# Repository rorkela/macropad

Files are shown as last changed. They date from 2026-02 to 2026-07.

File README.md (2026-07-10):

# EE2504: Hybrid Macropad (Wired + Dongle)

## Team

| Name | Roll Number |
|---|---|
| Sarthak Kumar Mishra |EE24BTECH11221|
| Naman Singh |EE24BTECH11216|
| Dhawal Saini |EE24BTECH11015|
| Sidharth V |EE24BTECH11224|
| Vantaku Sai Yashwant |EE24BTECH11225|
| Sriram Nulu |EE24BTECH11217|

## Details
- 2 Layer PCB for Macropad+Dongle Pair
- STM32F103C8T6 Based
- Programmed with `libopencm3`
- ssd1306 display integrated
- CAD Model designed to be 3D Printed for keycaps, encoder caps and casing.
- `microui` based key-map programming interface

## Instruction
1. Make the libraries (`libopencm3`)
2. Make and flash bootloader using `make flash`
3. Make and flash macropad firmware using `make flash` or the dfu script
4. Generate keymaps and flash using `mapping_gen`
# Current Status
- [x] PCB Ordered
## Wired
- [x] Bootloader Firmware
- [x] USB HID Firmware
- [x] DFU Firmware
- [x] Encoder Firmware
- [x] Display Firmware
- [x] All module integration
- [x] Multi key mapping
- [ ] Multi key sequential mapping

## Wireless
- [x] Dongle testing
- [x] nRF24L01 Firmware
- [ ] Battery Charging check
- [ ] Soldering SMD Mosfet + nRF modules
- [ ] Replacing PROG resistor for TP4056 module
- [ ] Complete Integration
## Other
- [x] Mapping generation and flashing with DFU
- [x] GUI
- [ ] Size Optimization for keymaps

## Images



## Links
- [CAD Model (Onshape)](https://cad.onshape.com/documents/8695aacad1c4b6aaf32709eb/w/c4719be3eaa84105acadf71a/e/89d918a88e3d346d4846fa41)

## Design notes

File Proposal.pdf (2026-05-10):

# Project Proposal: Design of a Hybrid-Mode Programmable Mechanical Macropad

EE24BTECH11224 Sidharth V
EE24BTECH11225 V Sai Yashwant EE24BTECH11221 Sarthak Mishra EE24BTECH11217 N Sri Ram
EE24BTECH11216 Naman Singh EE24BTECH11015 Dhawal Saini

# Github Link (https://github.com/rorkela/macropad)

## Contents

## Problem Statement

The modern technical workflow on computers relies heavily on complex, multi-key shortcuts. While commerical macro-input solutions, like the macropads exist, they present three critical barriers:

- High Cost-to-Value Ratio: Entry-level wired macropad often exceed ₹3,000. Our design can be cheaper per unit if ordered in bulk.
- Reliability & Software Constraints: Most affordable options are imported with closed-source software that presents reliability issues.
- Lack of Flexibility: They offer limited firmware customizability, minimizing the flexibility of usage in changing profiles, cross-platform connections, etc.
- Project Objective: To address workflow inefficiencies on computers by developed a power-efficient, dual mode (wireless + wired), and cost-effective Macropad.

## Proposed Solution

To bridge this gap, we propose to develop a Hybrid-Mode Custom Mechanical Macropad. This project prioritizes making low-latency and programmable macropad.

Key Features/Objectives:
- Mechanical Keys and Rotary Encoders: 9-key mechanical input array and dual rotary encoders to provide tactile, high-precision shortcuts.
- Dual-Path Connectivity: Transition between wired USB protocol and a low-latency 2.4GHz wireless link using the nRF24L01 protocol.
- Low Latency: By utilizing a Direct-Mapped GPIO Architecture instead of a scannable matrix, the devices reduces latency and achieves near true N-Key Rollover (NKRO) and eliminates the problems like ghosting (failing to detect pressed keys) and phantom keys (detecting unpressed keys).
- Programmable Firmware: A dedicated OLED display to display the the current profile, i.e, the key mapping and dedicated rotary encoder to switch profiles.
- Platform-Agnostic and Standard HID Device Functionality.
- Replaceable Hot Keys: Using hot-swappable mechanical sockets to replace physical keys whenever required.

## Device Architecture

This Macropad is built around STM32F103C8T6 (Cortex-M3) microcontroller, selected for it’s superior processing power compared to 8-bit alternatives and sufficient GPIO count for scanning the key matrix and the interfaces. The architecture is primarily split into two primary parts:
- The Macropad: Integrates the IO interface, the Power Management System and the Communication Module.
- The Dongle: A compact USB-interfaced unit, which receives data packets from the Macropad and translates to the standard HID commands.

### Block Diagram

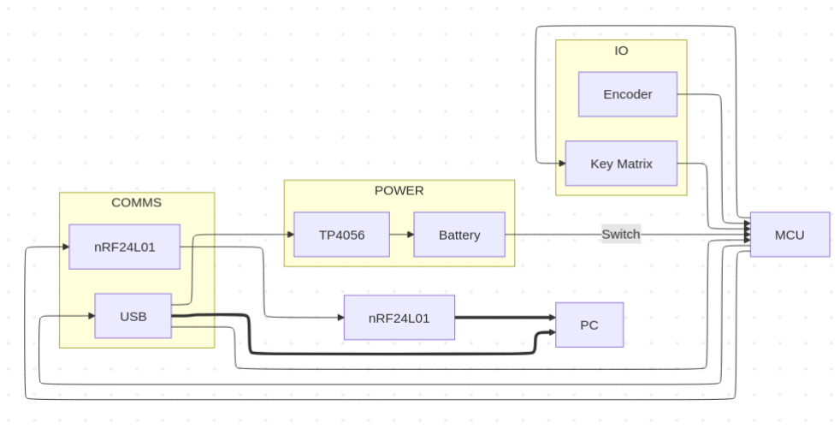
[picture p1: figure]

### Communication

This design comes with dual-modes for communication, allowing the user to switch between the wired USB and the standard 2.4GHz wireless mode.

Wired Mode
- The microcontroller automatically works in wired mode when connected via USB, i.e, if a 5V VBUS signal is detected.
- Dataflow: Key Matrix → STM32 → USB Data Lines (D + / D −) → PC
- The Macropad uses the incoming power from the port and the TP4056 power module simultaneously recharge the battery in the wired mode.
- The design follows the standard schematics for the USB 2.0 Type-C ports.

Wireless Mode
- The microcontroller automatically works in wireless mode when not connected via USB and switches to battery power.
- The nRF24L01 module is used for transmitting and receiving via the SPI (Serial Peripheral Interface) protocol.
- The design follows the following datasheet https://www.elprocus.com/nrf24l01/ , which includes the connections to the microcontroller.

Dongle
- The Dongle uses separate nRF24L01 module and microcontroller for receiving and handling the HID respectively.
- The nRF24L01 and microcontroller communicate via the SPI protocol.
- The dongle can be connected to 6 different devices simultaneously.

### Power Management

The design supports seamless transitions between battery power (wired mode) and USB power (wireless mode).

Charging Circuit and Power Path Logic
- TP4056 Lithium-ion battery charger receives 5V DC from the USB Type-C port.
- The TP4056 schematic is designed on the master schematic instead of using the separate IC.
- An additional Diode protection circuitry, acting as a MUX, is used to protect the battery from the simultaneous charging and discharging activities. This ensures that the Macropad load uses the 5V USB power in wired mode and 3.7V Li-ion battery in wireless mode.
- In wireless mode, the Macropad load uses the battery power. TP4056 module manages this switching.

Voltage Regulation(5V/3.7V → 3.3V)
- This design includes both buck module and an LDO module.
- The Buck module is the primary regulator, preferred over the LDO module, because of its power efficiency and lower power dissipation.
- An LDO module is used as a safety alternative for voltage regulation.

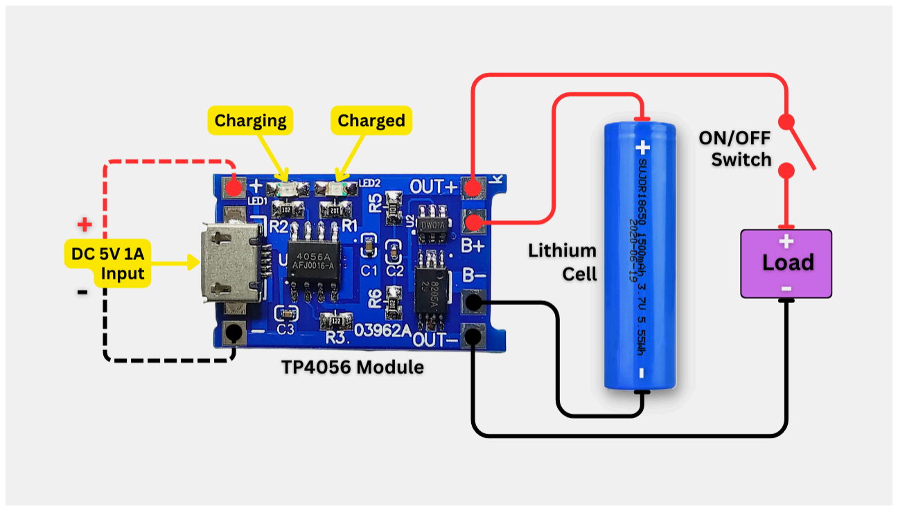
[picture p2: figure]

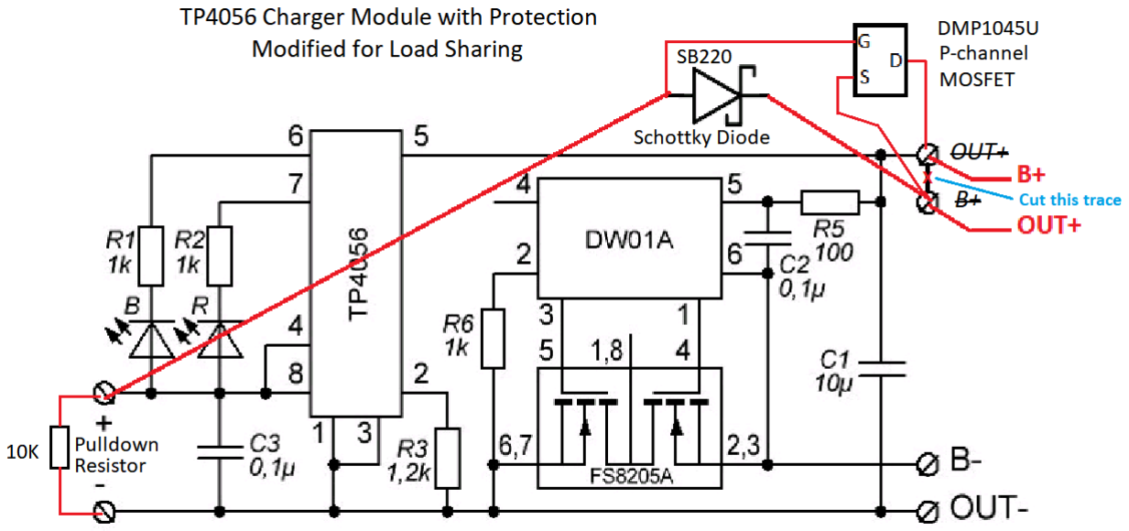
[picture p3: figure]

Figure 1: Reference: Arduino Forums (https://forum.arduino.cc/t/tp4056-circuit-schematic/1404367/8)

Efficiency and Battery Life
- Assuming worst case current draw to be 200mA and under constant use(nRF module does not sleep+Active display+MCU under load) and 2600MAh battery life. If we use 60% of the effective battery life, total uptime comes out to be 7.8 Hours.
- Under Idle situations may expect 24+ hours but requires actual hardware implementation to test.

### I/O Interface

The I/O interface is the bridge between user and the microcontroller. This part comprises of Mechanical Keys, 2 Rotary Encoder, and the OLED Display.

Direct Mapped Key Inputs
- This design uses Direct-Mapped GPIO configuration for the 9 mechanical switches.
- Each key is directly connected to a dedicated GPIO pin.
- This results in near-zero latency and a true N-Key Rollover (NKRO) as every key is sensed independently unlike for key matrix, where the microcontroller scans for key presses.
- Hot-swap Keys: The keys are mounted via mechanical sockets, allowing install keys without soldering.

Rotary Encoder
- Each encoder has 5 pins: +3.3V, GND, CLK (Phase A), DT (Phase B), SW.
- Quadrature Signals (CLK & DT): These signals transmit “out-of-phase” pulses.
- Determining direction: The Clockwise rotation results in Phase A going high before Phase B and vice-versa for Counter-Clockwise rotation.
- Integrated Push Switch (SW): It is used for ?

Display
- A 0.96-inch OLED display is used to display: Active Profile: Current-Key map configuration. Connection Mode: Wired/Wireless Battery Life remaining (in %)
- The display interfaces via I2C protocol, requiring only two wires (SDA and SCL) to handle the visual data.
- The firmware inside STM32 process the input signals for the display.

### Firmware

Bootloader
- A custom USB-DFU bootloader is used to to enable firmware upgrade and programmable keys through USB.

HID
- The macropad implements two HID interfaces, keyboard and system control.
- The keyboard interface is used for macros that use the keys present in a regular 106 key keyboard.
- The system control interface allows other bindings such as device volume, brightness and power controls.
- The code has been tested on Linux and Windows.
- In wireless operation, the macropad sends the usb reports to the dongle, and the dongle acts as a HID device and forwards this report to the host.

Profiles
- The Profiles and key mappings are stored outside the main firmware. The firmware reads the data from memory based on the selected profile.
- This allows changing the key mappings without having to re-flash the main HID firmware

Dongle
- The dongle acts as a USB device with multiple interfaces
- The code can be extended to support multiple device connections, using a different interface for each device connected to the nRF24L01

## Schematic

This is the final schematic.

NRST 7 | BOOT0 44 | PD0 5 | PD1 6 | PC13 2 | PC14 3 | PC15 4 | PB0 18 | PB1 19 | PB2 20 | PB3 39 | PB4 40 | PB5 41 | PB6 42 | PB7 43 | PB8 45 | PB9 46 | PB10 21 | PB11 22 | PB12 25 | PB13 26 | PB14 27 | PB15 28 | VBAT

# 10k GND GND

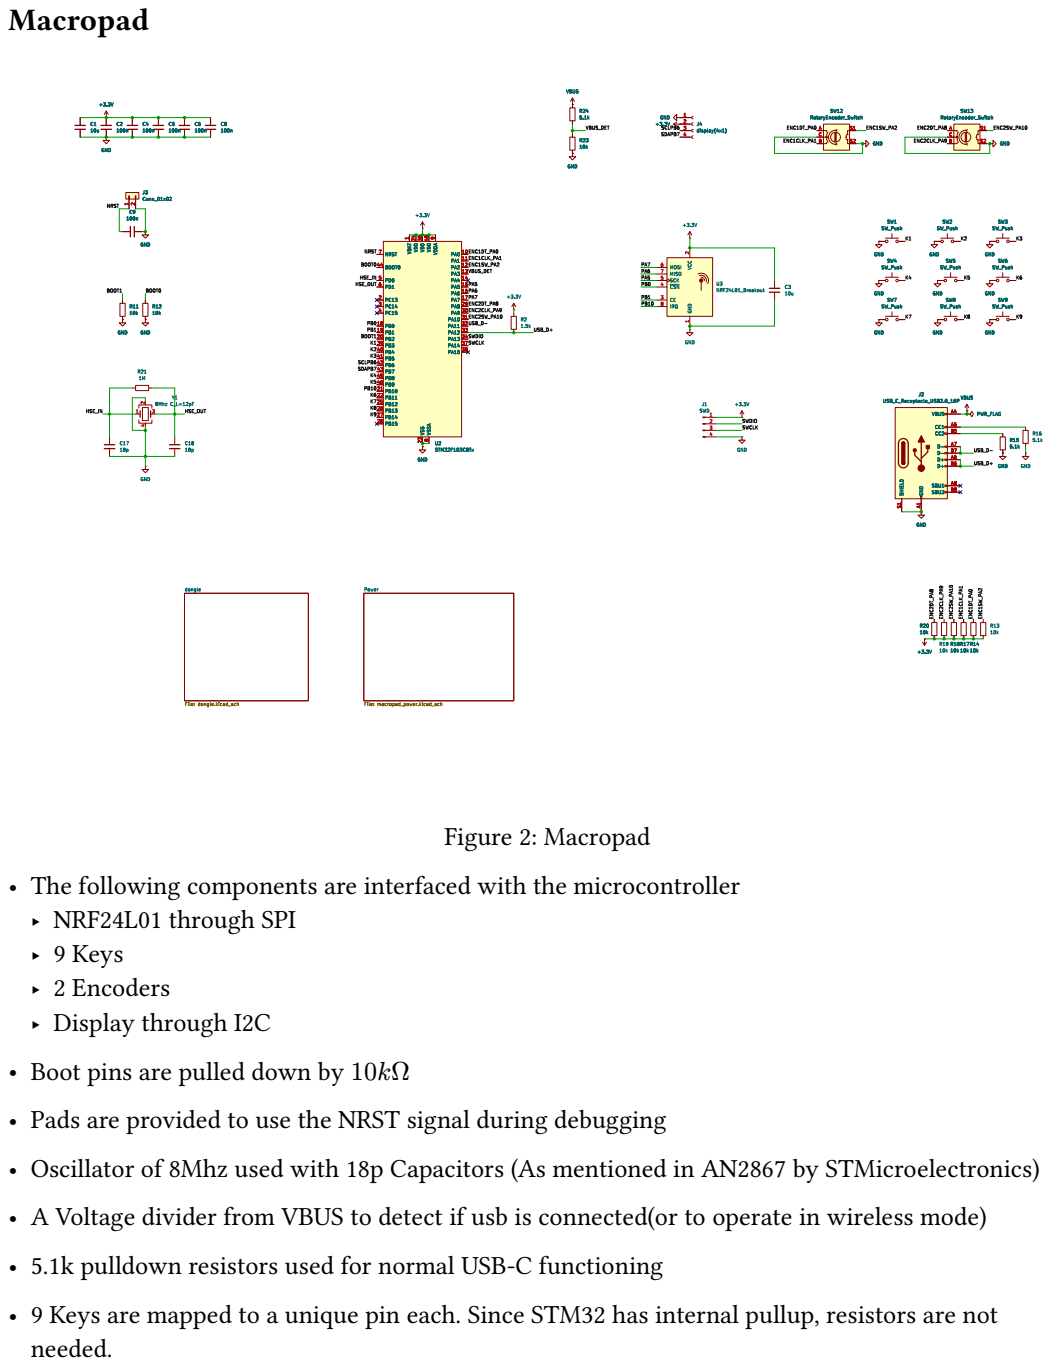
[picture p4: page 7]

1 VDD 24 VDD 36 VSS 23 VDD 48 VSSA

• The following components are interfaced with the microcontroller
‣ NRF24L01 through SPI
‣ 9 Keys
‣ 2 Encoders
‣ Display through I2C

• Boot pins are pulled down by 10kΩ

• Pads are provided to use the NRST signal during debugging

• Oscillator of 8Mhz used with 18p Capacitors (As mentioned in AN2867 by STMicroelectronics)

• A Voltage divider from VBUS to detect if usb is connected(or to operate in wireless mode)

• 5.1k pulldown resistors used for normal USB-C functioning

• 9 Keys are mapped to a unique pin each. Since STM32 has internal pullup, resistors are not
needed.

18p | C13
10n | C20

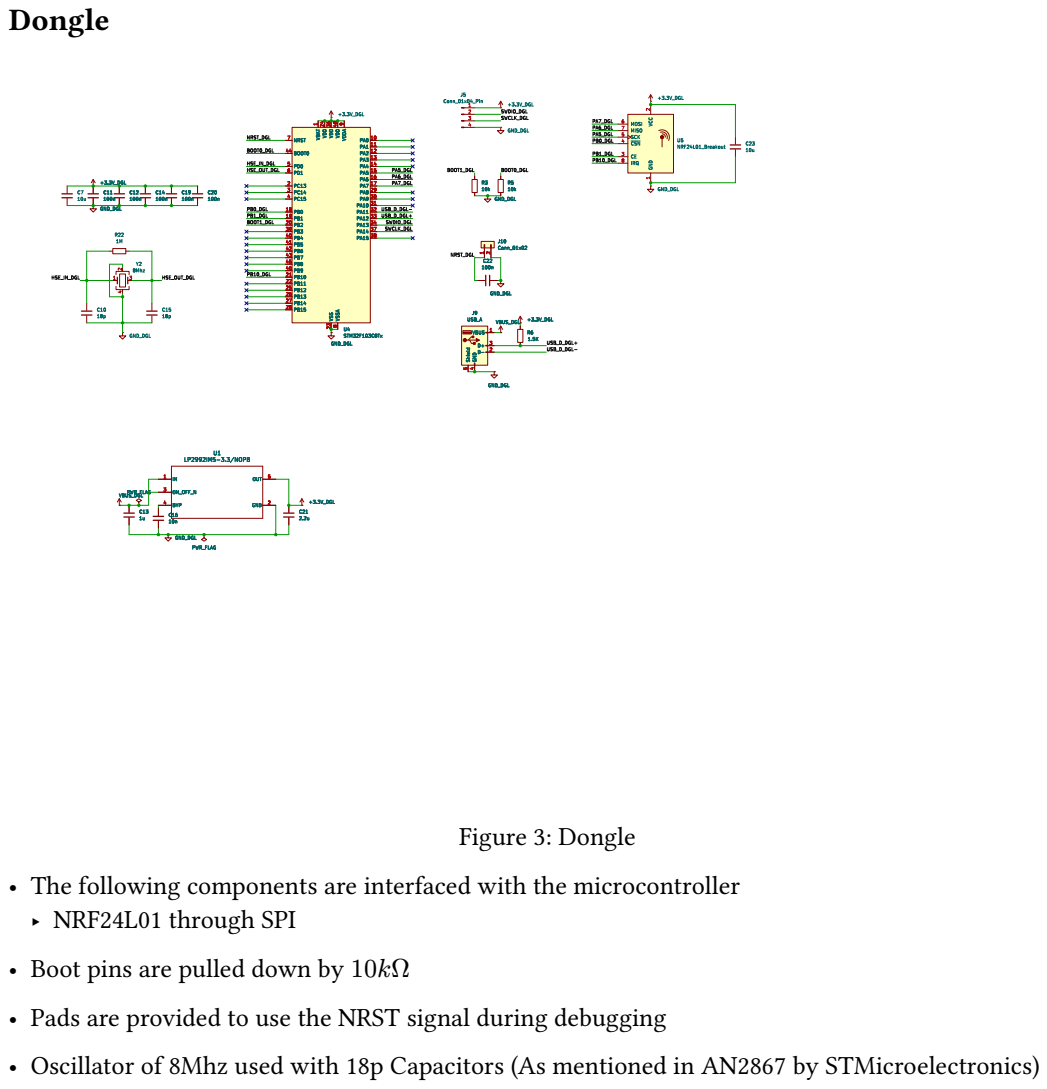
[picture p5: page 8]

1 VDD 24 VDD 36 VSS 23 VDD 48 VSSA

• The following components are interfaced with the microcontroller
‣ NRF24L01 through SPI

• Boot pins are pulled down by 10kΩ

• Pads are provided to use the NRST signal during debugging

• Oscillator of 8Mhz used with 18p Capacitors (As mentioned in AN2867 by STMicroelectronics)

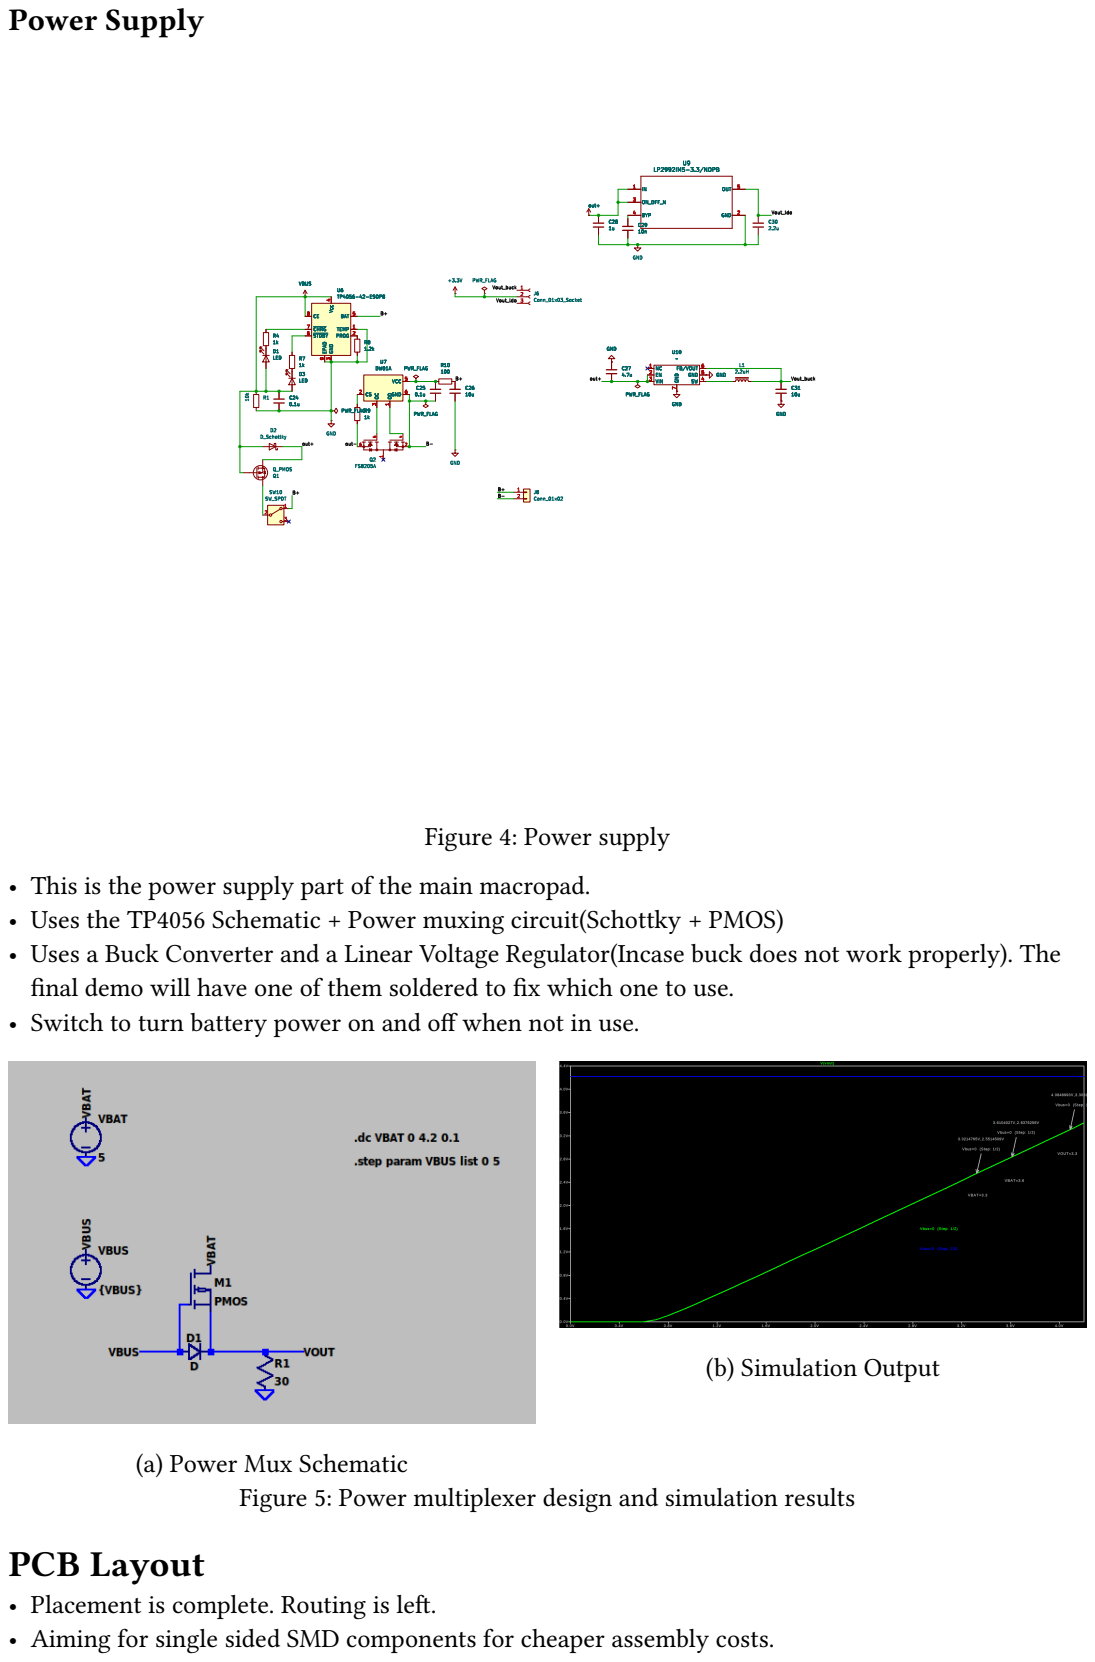
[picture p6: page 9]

7 FB/VOUT 6 GND 5 SW 4 PWR_FLAG

7 FB/VOUT 6 GND 5 SW 4 U10~

• This is the power supply part of the main macropad.
• Uses the TP4056 Schematic + Power muxing circuit(Schottky + PMOS)
• Uses a Buck Converter and a Linear Voltage Regulator(Incase buck does not work properly). The
final demo will have one of them soldered to fix which one to use.
• Switch to turn battery power on and off when not in use.

Figure 5: Power multiplexer design and simulation results

PCB Layout
• Placement is complete. Routing is left.
• Aiming for single sided SMD components for cheaper assembly costs.

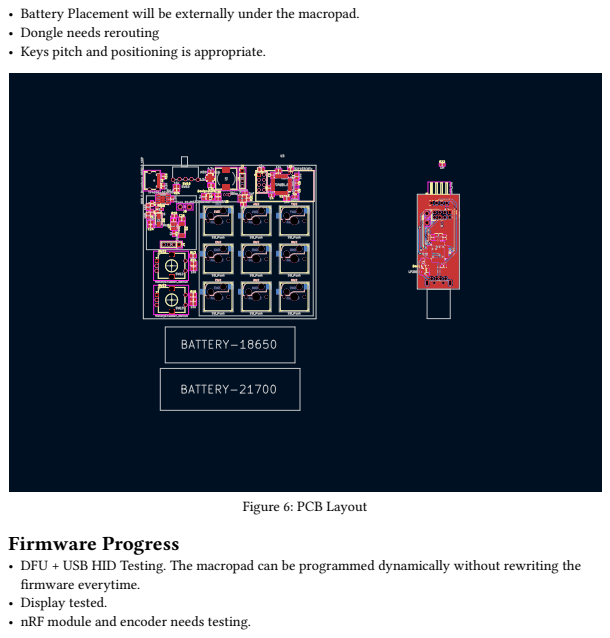
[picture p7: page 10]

• Battery Placement will be externally under the macropad.
• Dongle needs rerouting
• Keys pitch and positioning is appropriate.

Figure 6: PCB Layout

Firmware Progress
• DFU + USB HID Testing. The macropad can be programmed dynamically without rewriting the
firmware everytime.
• Display tested.
• nRF module and encoder needs testing.

## 3D Printing Progress

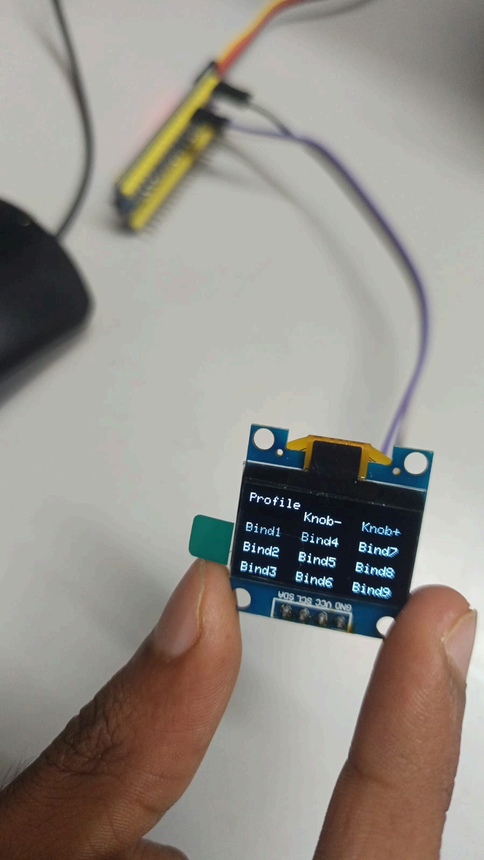
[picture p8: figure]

We did a test 3d print of a key. We will test it later. The model was taken from online (Link). (https://www.printables.com/model/118708-simple-cherry-mx-keycap)

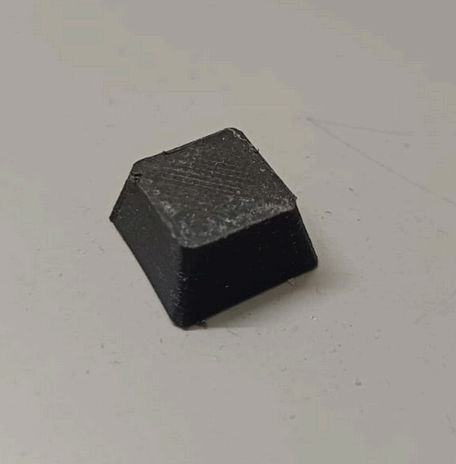
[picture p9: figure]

,

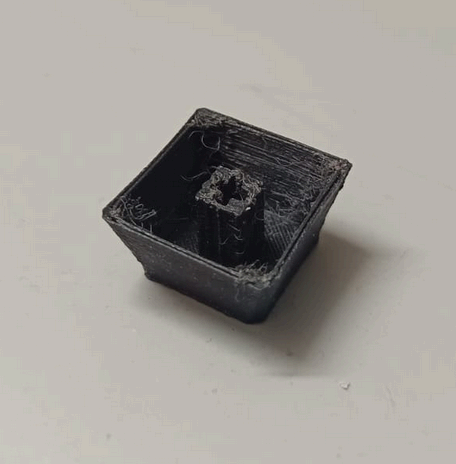
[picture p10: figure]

Figure 8: 3D printed keycap

## Cost Estimates

Sl No | Component Name | Unit Cost (₹) | Qty | Subtotal (₹)
1 | STM32F103C8T6 | 176.00 | 2 | 352.00
2 | M177 NRF24L01 Module | 71.00 | 2 | 142.00
3 | Mechanical Keys (Pack of 10) | 300.00 | 1 | 300.00
4 | Kailh Hot-swap Socket (Pack of 10) | 80.00 | 1 | 80.00
5 | TP4056 Module | 15.00 | 1 | 15.00
6 | Battery Protection (DW01A) | 4.00 | 1 | 4.00
7 | FS8205A Dual MOSFET | 8.00 | 1 | 8.00
8 | TP4056 IC | 7.00 | 1 | 7.00
9 | 0.96 inch OLED Module | 200.00 | 1 | 200.00
10 | Lithium Ion Battery | 0.00 | 1 | 0.00
11 | Rotary Encoder Module | 50.00 | 2 | 100.00
12 | Voltage Regulator (LP2992) | 14.00 | 2 | 28.00
13 | Crystal Oscillator (8MHz) | 10.00 | 2 | 20.00
14 | Buck Converter (RT8010) | 45.48 | 1 | 45.48
15 | USB A Connector | 2.64 | 1 | 2.64
16 | USB-C Receptacle | 3.95 | 1 | 3.95
17 | Schottky Diode (SS34) | 2.00 | 2 | 4.00
18 | PMOS (SI2305CDS) | 10.00 | 1 | 10.00
19 | Slide Switch (SPDT) | 7.00 | 2 | 14.00
20 | Pin Headers (1xN) | 2.00 | 14 | 28.00
21 | Inductor 2.2uH | 15.00 | 1 | 15.00
22 | Cap 4.7uF | 7.00 | 1 | 7.00
23 | Cap 10uF | 6.00 | 9 | 54.00
24 | Res 10K Ohm | 0.35 | 5 | 1.75
25 | Res 1K Ohm | 0.19 | 3 | 0.57
26 | Cap 0.1uF | 1.69 | 14 | 23.66
27 | Res 1.2K Ohm | 0.15 | 1 | 0.15
28 | Res 100 Ohm | 0.40 | 3 | 1.20
29 | Res 1.5k | 1.00 | 2 | 2.00
30 | Res 5.1k | 1.00 | 2 | 2.00
31 | Cap 18pF | 1.36 | 4 | 5.44
32 | Cap 1uF | 1.17 | 2 | 2.34
33 | LEDs (0805) | 1.55 | 4 | 6.20

34 | Cap 10nF | 0.63 | 1 | 0.63
35 | Cap 2.2uF | 1.00 | 1 | 1.00
Grand Total | | | | ₹1,586.04

Note: Lithium ion battery (Sl No 10) is a lab-sourced item and is not included in the total cost.

## Component Availability

Here is the list of components which can readily be procured from Robu.

Sl | Component Name | Part Number | Package | Vendor Link
1 | STM32F103C8T6 | STM32F103C8T6 | LQFP-48 | Robu.in (https://robu.in/product/stm32f103c8t6-lqfp-48-arm-microcontrollers-mcu/)
2 | nRF24L01 Module | NRF24L01 | PCB 4x2 | Robu.in (https://robu.in/product/m177-nrf24l01-2-4ghz-antenna-wireless-transceiver-module/)
3 | Mechanical Keys | Gateron Pro | 5-Pin TH | Meckeys (https://meckeys.com/shop/accessories/keyboard-accessories/key-switches/gateron-mechanical-pro-switch-5pin/)
4 | Kailh Hotswap Socket | CPG151101S11-16 | SMD | Meckeys (https://meckeys.com/shop/accessories/keyboard-accessories/key-switches/kailh-hot-swap-socket/)
5 | TP4056 Module | TP4056 | PCB Module | Robu.in (https://robu.in/product/tp4056-1a-li-ion-lithium-battery-charging-module-with-current-protection-type-c/)
6 | Battery Protection | DW01A | SOT-23-6 | Robu.in (https://robu.in/product/dw01a-4-3v-lithium-ion-lithium-polymer-battery-protection-ic-6pin-sot-23/)
7 | FS8205A MOSFET | FS8205A | SMD | Robu.in (https://robu.in/product/1-month-warranty-398/)
8 | TP4056 IC | TP4056 | SMD | Evelta (https://evelta.com/tp4056-4-2v-1a-li-lon-battery-charger-with-thermal-regulation/)
9 | 0.96″ OLED Module | SSD1306 | PCB 4-pin | Robu.in (https://robu.in/product/0-96-inch-yellow-yellow-blue-oled-lcd-led-display-module/)
10 | Li-ion Battery | Lab ID: AA546 | Cell | Lab Item
11 | Rotary Encoder | KY-040 | 5 Pin Header | Robu.in (https://robu.in/product/m274-360-degree-rotary-encoder-module-brick-sensor/)
12 | Voltage Regulator | LP2992-3.3V | SOT-23-5 | Robu.in (https://robu.in/product/lp2992im5-3-3-nopb-texas-instruments-fixed-ldo-voltage-regulator-2-2v-to-16v-450mv-dropout-3-3vout-250maout-sot-23-5/)
13 | Crystal Oscillator | 8MHz | SMD 3225 | Robu.in (https://robu.in/product/x32258mob4si-yxc-crystal-oscillators-8mhz-surface-mount-crystal-12pf-%c2%b110ppm-%c2%b120ppm-smd3225-4p-crystals-rohs/)
14 | Buck Regulator | RT8010-33GQW | 6-WDFN | DigiKey (https://www.digikey.in/en/products/detail/richtek-usa-inc/RT8010-33GQW/2545950)
15 | USB A Connector | U-G-O4DD | Type A Male | Robu.in (https://robu.in/product/u-g-o4dd-w-1-hroparts-1a-1-4p-male-40%e2%84%8385%e2%84%83-type-a-usb-connectors-rohs/)
16 | USB-C Receptacle | U263-163N | SMD 16P | Robu.in (https://robu.in/product/u263-163n-4ws1735-xkb-5a-1-16p-female-25%E2%84%8385%E2%84%83-type-c-smd-usb-connectors-rohs/)
17 | Schottky Diode | SS34 | DO-214 | Robu.in (https://robu.in/product/ss34-slkor-40v-500mv3a-3a-smado-214ac-schottky-diodes-rohs/)
18 | P-MOSFET | SI2305CDS | SOT-23 | Robu.in (https://robu.in/product/si2305cds-t1-ge3-vishay-si2305cds-t1-ge3-power-mosfet-p-channel-8-v-5-8-a-0-028-ohm-sot-23-surface-mount/)
19 | Slide Switch | SS12F23L5 | Plugin | Robu.in (https://robu.in/product/1-month-warranty-690/)
20 | Pin Headers | 2.54mm Machined | Through Hole | Robu.in (https://robu.in/product/361030115sg111901-jiln-2-54x3-0machined-pin-header-1x15p-180-l11-96-upper-pinpoint0-60-bottom-pinpoint0-50-au1u-pps/)
21 | Inductor 2.2uH | CDRH104R | SMD | Robu.in (https://robu.in/product/cdrh104r-2-2%ce%bch-power-inductor-pack-of-5/)
22 | Cap 4.7uF | GRM188Z71C475 | 0603 | Robu.in (https://robu.in/product/grm188z71c475ke21d-murata-electronics-16v-4-7uf-x7r-%c2%b110-0603-multilayer-ceramic-capacitors-mlcc-smd-smt-rohs/)
23 | Cap 10uF | GRT21BR61C106 | 0805 | Robu.in (https://robu.in/product/grt21br61c106ke01l-murata-electronics-16v-10uf-x5r-%c2%b110-0805-multilayer-ceramic-capacitors-mlcc-smd-smt-rohs/)
24 | Res 10K Ohm | RC0805FR-0710K | 0805 | Robu.in (https://robu.in/product/rc0805fr-0710kl-yageo-res-thick-film-0805-10k-ohm-1-0-125w1-8w-%c2%b1100ppm-c-pad-smd-t-r/)
25 | Res 1K Ohm | AC0603FR-071K | 0603 | Robu.in (https://robu.in/product/ac0603fr-071kl-yageo-res-thick-film-0603-1k-ohm-1-0-1w1-10w-%c2%b1100ppm-c-pad-smd-t-r-automotive-aec-q200/)
26 | Cap 0.1uF | AC0603JRX7R9BB | 0603 | Robu.in (https://robu.in/product/ac0603jrx7r9bb104-yageo-cap-ceramic-0-1uf-50v-x7r-5-pad-smd-0603-125c-automotive-aec-q200-t-r/)
27 | Res 1.2K Ohm | AC0603FR-071K2 | 0603 | Robu.in (https://robu.in/product/ac0603fr-071k2l-yageo-res-thick-film-0603-1-2k-ohm-1-0-1w1-10w-%c2%b1100ppm-c-pad-smd-t-r-automotive-aec-q200/)
28 | Res 100 Ohm | AC0201FR-07100R | 0603 | Robu.in (https://robu.in/product/ac0201fr-07100rl-yageo-smd-chip-resistor-100-ohm-%c2%b1-1-50-mw-0201-0603-metric-thick-film-general-purpose/)
29 | Res 1.5K Ohm | RT0603FRE071K5 | 0603 | Robu.in (https://robu.in/product/rt0603fre071k5l-yageo-100mw-thin-film-resistor-%c2%b150ppm-%e2%84%83-%c2%b11-1-5k%cf%89-0603-chip-resistor-surface-mount-rohs/)
30 | Res 5.1K Ohm | RT0603FRE075K1 | 0603 | Robu.in (https://robu.in/product/rt0603fre075k1l-yageo-100mw-thin-film-resistor-75v-%c2%b150ppm-%e2%84%83-%c2%b11-1-5-1k%cf%89-0603-chip-resistor-surface-mount-rohs/)
31 | Cap 18pF | GCM0335C1H180 | 0603 | Robu.in (https://robu.in/product/gcm0335c1h180fa16d-murata-smd-multilayer-ceramic-capacitor-18-pf-50-v-0201-0603-metric-%c2%b1-1-c0g-np0-gcm/)
32 | Cap 1uF | UMK212B7105K | 0805 | Robu.in (https://robu.in/product/umk212b7105kght-taiyo-cap-ceramic-1uf-50v-x7r-10-pad-smd-0805-125c-low-esr-automotive-aec-q200-t-r/)
33 | LEDs (Red) | 17-21SURC/S530 | 0805 | Robu.in (https://robu.in/product/17-21surc-s530-a3-4t-everlight-elec/)
34 | Cap 10nF | Ceramic MLCC | 0603 | Robu.in (https://robu.in/product/10nf-0603-surface-mount-multilayer-ceramic-capacitor-pack-of-50/)
35 | Cap 2.2uF | TMK107BBJ225 | 0603 | Robu.in (https://robu.in/product/tmk107bbj225kaht-taiyo-cap-ceramic-2-2uf-25v-x5r-10-pad-smd-0603-85c-low-esr-automotive-aec-q200-t-r/)

Item | Count
Keycaps | 9
Macropad Casing | 1
Dongle Casing | 1

Table 1: 3D Printing Estimates

Some expenses in procuring modules for testing before PCB fabrication are not included.

Approximate PCB Quotation

This is based on assembly configuration and very rough PCB Area.

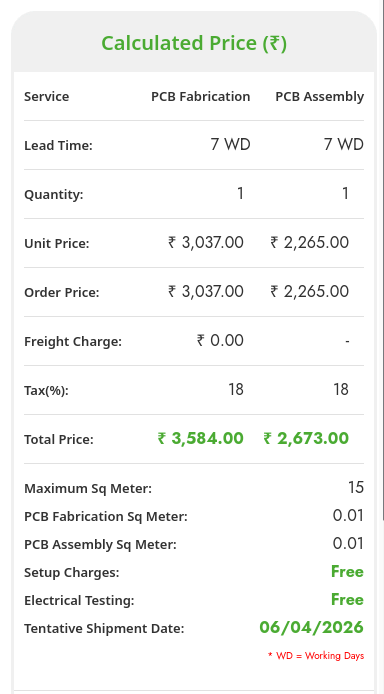
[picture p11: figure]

Figure 9: Approximate PCBPower Quotation

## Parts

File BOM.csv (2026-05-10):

Sl No | Components' name | Components' Value | Manufacturer Part Number (MPN) | Link to Datasheet | Package/Footprint | Quantity | Vendor Link-1 | Vendor Link-2 | Vendor Link-3 | Vendor Link-4
1 | STM32F103C8T6 | 176 | STM32F103C8T6 | https://www.st.com/resource/en/datasheet/stm32f103c8.pdf | SMD LQFP-48 | 2 | https://robu.in/product/stm32f103c8t6-lqfp-48-arm-microcontrollers-mcu/ | https://evelta.com/stm32f103c8t6---32bit-arm-cortex-m3-microcontroller-72mhz-64kb-flash-48-pin-lqfp/ | https://www.digikey.in/en/products/detail/stmicroelectronics/STM32F103C8T6/1646338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
2 | M177 NRF24L01 2.4GHz Antenna Wireless Transceiver Module | 71 | NRF24L01 | https://docs.nordicsemi.com/bundle/nRF24L01P_PS_v1.0/resource/nRF24L01P_PS_v1.0.pdf | PCB(4x2 pins) | 2 | https://robu.in/product/m177-nrf24l01-2-4ghz-antenna-wireless-transceiver-module/ | https://robocraze.com/products/nrf24l01-ultra-low-power-2-4ghz-rf-wireless-transceiver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 | https://probots.co.in/nrf24l01-rf-wireless-transceiver-2-4ghz-module.html | https://quartzcomponents.com/products/nrf24l01-24f-rf-transiver-module
3 | Mechanical Keys(Pack of 10) | 300 | NA | NA | 5 Pin Through Hole | 1(Pack of 10) | https://meckeys.com/shop/accessories/keyboard-accessories/key-switches/gateron-mechanical-pro-switch-5pin/ | https://amzn.in/d/090QFwbe | https://www.amazon.in/Buildcon-Linear-Keyboard-Compatible-Keyboards/dp/B0FQTZMC9R | https://meckeys.com/shop/accessories/keyboard-accessories/key-switches/cherry-mx-rgb-switch/
4 | Kailh Hot-swap Socket(Pack of 10)) | 80 | CPG151101S11-16 | https://www.lcsc.com/product-detail/C5156480.html | SMD | 1(Pack of 10) | https://meckeys.com/shop/accessories/keyboard-accessories/key-switches/kailh-hot-swap-socket/ | https://neomacro.in/products/kailh-mx-hotswap-socket?variant=49467139227926
5 | TP4056 Module | 15 | TP4056 | NA | PCB(Module) | 1 | https://robu.in/product/tp4056-1a-li-ion-lithium-battery-charging-module-with-current-protection-type-c/ | https://robocraze.com/products/tp4056-battery-charger-c-type-module-with-protection-1 | https://robokits.co.in/batteries-chargers/charge-protection-circuit/tp4056-1a-5v-li-ion-battery-charge-discharge-protection-module-type-c-usb | https://quartzcomponents.com/products/tp4056-battery-charging-protection-module-type-c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
6 | Battery Protection (DW01A) | 4 | DW01A | https://mm.digikey.com/Volume0/opasdata/d220001/medias/docus/7833/DW01A%20SOT-23-6.PDF | SMD | 1 | https://robu.in/product/dw01a-4-3v-lithium-ion-lithium-polymer-battery-protection-ic-6pin-sot-23/ | https://www.digikey.in/en/products/detail/shenzhen-slkormicro-semicon-co-ltd/DW01A/28143000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
7 | FS8205A | 8 | FS8205A | https://mm.digikey.com/Volume0/opasdata/d220001/medias/docus/7158/5272_FS8205A.pdf | SMD | 1 | https://robu.in/product/1-month-warranty-398/ | https://www.digikey.in/en/products/detail/evvo/FS8205A/26220994?msockid=33cd2190f636665f1fcb3795f7df6785
8 | TP4056 | 7 | TP4056 | https://www.digikey.com/htmldatasheets/production/2049110/0/0/1/tp4056.html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 | SMD | 1 | https://evelta.com/tp4056-4-2v-1a-li-lon-battery-charger-with-thermal-regulation/ | https://robu.in/product/1-month-warranty-1253/
9 | 0.96 inch Yellow-Blue OLED Display Module | 200 | NA | NA | PCB(4 pins in sequence GND VDD SCK SDA) | 1 | https://robu.in/product/0-96-inch-yellow-yellow-blue-oled-lcd-led-display-module/ | https://quartzcomponents.com/products/oled-display-0-96-inch-i2c-interface-4-pin-blue-ssd1306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 | https://robocraze.com/products/0-96in-oled-display-module-4pin?_pos=1&_sid=e498cf4c5&_ss=r | https://robocraze.com/products/0-96in-oled-display-module-4pin?_pos=1&_sid=821c7db53&_ss=r
10 | Lithium ion battery | available in lab | AA546(Lab item ID),BPK-QC1411 | NA | NA | 1 | https://robu.in/product/samsung-inr18650-25r-2500mah-li-ion-battery/ | https://robu.in/product/dmegc-inr21700-45e-3-7v-4500mah-li-ion-battery/
11 | M274 360-Degree Rotary Encoder Sensor Brick Module | 50 | KY-040 | https://www.alldatasheet.com/datasheet-pdf/pdf/1648739/JOY-IT/KY-040.html | 5 Pin Header | 2 | https://robu.in/product/m274-360-degree-rotary-encoder-module-brick-sensor/ | https://electronicspices.com/product/ky-040-rotary-encoder-module-brick-sensor-for-development-board-360-degree | https://robocraze.com/products/rotary-encoder-module?_pos=1&_sid=a3f2cd847&_ss=r | https://techdelivers.com/360-degree-rotary-encoder-module-m274-brick-sensor-incremental-type-price-india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
12 | Voltage Regulator(LP2992IM5-3.3V) | 14 | LP2992IM5-3.3/NOPB | https://www.ti.com/lit/ds/symlink/lp2992.pdf?ts=1742480137364&ref_url=https%253A%252F%252F | SOT-23-5 | 2 | https://robu.in/product/lp2992im5-3-3-nopb-texas-instruments-fixed-ldo-voltage-regulator-2-2v-to-16v-450mv-dropout-3-3vout-250maout-sot-23-5/
13 | Crystal Oscillator(8MHz) | 10 | X32258MOB4SI | https://www.lcsc.com/datasheet/C2682775.pdf | SMD | 2 | https://robu.in/product/x32258mob4si-yxc-crystal-oscillators-8mhz-surface-mount-crystal-12pf-%c2%b110ppm-%c2%b120ppm-smd3225-4p-crystals-rohs/
14 | buck(RT8010-33GQW) | 45.48 | RT8010-33GQW | https://www.richtek.com/assets/product_file/RT8010=RT8010A/DS8010A-13.pdf | SMD(6-WDFN) | 1 | https://www.digikey.in/en/products/detail/richtek-usa-inc/RT8010-33GQW/2545950
15 | USB A | 2.64 | U-G-O4DD-W-1-Hroparts-1A | https://robu.in/wp-content/uploads/2025/08/C2910540.pdf | https://robu.in/wp-content/uploads/2025/08/C2910540.pdf | 1 | https://robu.in/product/u-g-o4dd-w-1-hroparts-1a-1-4p-male-40%e2%84%8385%e2%84%83-type-a-usb-connectors-rohs/ | https://robu.in/product/usb-a-type-plug-male-pcb-r-a-connector-pack-of-5/
16 | USB - c receptacle | 3.95 | U263-163N-4WS1735-XKB-5A | https://robu.in/wp-content/uploads/2025/08/C2931473.pdf https://www.helloxkb.com/public/images/pdf/U263-163N-4WS1735.pdf | https://robu.in/wp-content/uploads/2025/08/C2931473.pdf | 1 | https://robu.in/product/u263-163n-4ws1735-xkb-5a-1-16p-female-25%E2%84%8385%E2%84%83-type-c-smd-usb-connectors-rohs/
17 | schottky diode | 2 | SS34 | https://www.onsemi.com/download/data-sheet/pdf/ss39-d.pdf | DO-214 | 2 | https://robu.in/product/ss34-slkor-40v-500mv3a-3a-smado-214ac-schottky-diodes-rohs/ | https://www.digikey.com/en/products/detail/onsemi/SS34/1052384?msockid=33cd2190f636665f1fcb3795f7df6785 | https://www.digikey.in/en/products/detail/diotec-semiconductor/SB220/22191291
18 | PMOS(SI2305CDS-T1-GE3) | 10 | SI2305CDS-T1-GE3 | https://robu.in/wp-content/uploads/2025/06/R231218.pdf | SOT-23 | 1 | https://robu.in/product/si2305cds-t1-ge3-vishay-si2305cds-t1-ge3-power-mosfet-p-channel-8-v-5-8-a-0-028-ohm-sot-23-surface-mount/ | https://www.mouser.in/ProductDetail/Vishay-Semiconductors/SI2305CDS-T1-GE3?qs=45wPT2wjtGlJ9EjSomimkg%3D%3D
19 | SS12F23L5-XKB-300mA Single Pole Double Throw (SPDT) 50V 50V 300mA 10,000 times Black Plugin Slide Switches ROHS | 7 | SS12F23L5 | https://www.lcsc.com/datasheet/C2884749.pdf | https://www.lcsc.com/datasheet/C2884749.pdf | 2 | https://robu.in/product/1-month-warranty-690/
20 | Pin Headers(Any 1xN) | 14 | 361030115SG111901 |  | 2.54mm Through Hole | 2 | https://robu.in/product/361030115sg111901-jiln-2-54x3-0machined-pin-header-1x15p-180-l11-96-upper-pinpoint0-60-bottom-pinpoint0-50-au1u-pps/ | https://robu.in/product/361030130sg111901-jiln-2-54x3-0machined-pin-header-1x30p-180-l11-96-upper-pinpoint0-60-bottom-pinpoint0-50-au1u-pps/
21 | Inductor 2.2uH | 15 | CDRH104R 2.2uH |  | SMD | 1 | https://robu.in/product/cdrh104r-2-2%ce%bch-power-inductor-pack-of-5/ | https://sharvielectronics.com/product/cdrh104r-2-2uh-smd-power-inductor/
22 | Cap 4.7uF | 7 | GRM188Z71C475KE21D |  | SMD-0603 | 1 | https://robu.in/product/grm188z71c475ke21d-murata-electronics-16v-4-7uf-x7r-%c2%b110-0603-multilayer-ceramic-capacitors-mlcc-smd-smt-rohs/
23 | Cap 10uF | 9 | GRT21BR61C106KE01L |  | SMD-0805 | 6 | https://robu.in/product/grt21br61c106ke01l-murata-electronics-16v-10uf-x5r-%c2%b110-0805-multilayer-ceramic-capacitors-mlcc-smd-smt-rohs/
24 | Res 10K Ohm | 0.32 | RC0805JR-0710KL |  | SMD-0805 | 25 | https://robu.in/product/rc0805jr-0710kl-yageo-res-thick-film-0805-10k-ohm-5-0-125w1-8w-%c2%b1100ppm-c-pad-smd-t-r/ | https://robu.in/product/rc0805jr-0710kl-yageo-res-thick-film-0805-10k-ohm-5-0-125w1-8w-%c2%b1100ppm-c-pad-smd-t-r/
25 | Res 1K ohm | 0.19 | AC0603FR-071KL |  | SMD-0603 | 3 | https://robu.in/product/ac0603fr-071kl-yageo-res-thick-film-0603-1k-ohm-1-0-1w1-10w-%c2%b1100ppm-c-pad-smd-t-r-automotive-aec-q200/
26 | Cap 0.1uF | 1.69 | AC0603JRX7R9BB104 |  | SMD-0603 | 15 | https://robu.in/product/ac0603jrx7r9bb104-yageo-cap-ceramic-0-1uf-50v-x7r-5-pad-smd-0603-125c-automotive-aec-q200-t-r/
27 | Res 1.2K ohm | 0.15 | AC0603FR-071K2L |  | SMD-0603 | 1 | https://robu.in/product/ac0603fr-071k2l-yageo-res-thick-film-0603-1-2k-ohm-1-0-1w1-10w-%c2%b1100ppm-c-pad-smd-t-r-automotive-aec-q200/
28 | Res 100 ohm | 0.4 | AC0201FR-07100RL |  | SMD-0603 | 3 | https://robu.in/product/ac0201fr-07100rl-yageo-smd-chip-resistor-100-ohm-%c2%b1-1-50-mw-0201-0603-metric-thick-film-general-purpose/
29 | Res 1.5k | 1 | RT0603FRE071K5L |  | SMD-0603 | 2 | https://robu.in/product/rt0603fre071k5l-yageo-100mw-thin-film-resistor-%c2%b150ppm-%e2%84%83-%c2%b11-1-5k%cf%89-0603-chip-resistor-surface-mount-rohs/
30 | Res 5.1k | 1 | RT0603FRE075K1L |  | SMD-0603 | 3 | https://robu.in/product/rt0603fre075k1l-yageo-100mw-thin-film-resistor-75v-%c2%b150ppm-%e2%84%83-%c2%b11-5-1k%cf%89-0603-chip-resistor-surface-mount-rohs/
31 | Cap 18pF | 1.36 | GCM0335C1H180FA16D |  | SMD-0603 | 4 | https://robu.in/product/gcm0335c1h180fa16d-murata-smd-multilayer-ceramic-capacitor-18-pf-50-v-0201-0603-metric-%c2%b1-1-c0g-np0-gcm/
32 | Cap 1uF | 1.17 | UMK212B7105KGHT |  | SMD-0805 | 3 | https://robu.in/product/umk212b7105kght-taiyo-cap-ceramic-1uf-50v-x7r-10-pad-smd-0805-125c-low-esr-automotive-aec-q200-t-r/
33 | LEDs | 1.55 | 17-21SURC/S530-A3/4T |  | SMD-0805 | 4 | https://robu.in/product/17-21surc-s530-a3-4t-everlight-elec/
34 | Cap 10nF | 0.63 | NA |  | SMD-0603 | 2 | https://robu.in/product/10nf-0603-surface-mount-multilayer-ceramic-capacitor-pack-of-50/
35 | Cap 2.2uF | 1 | TMK107BBJ225KAHT |  | SMD-0603 | 2 | https://robu.in/product/tmk107bbj225kaht-taiyo-cap-ceramic-2-2uf-25v-x5r-10-pad-smd-0603-85c-low-esr-automotive-aec-q200-t-r/
36 | Res 1Meg | 0.68 | CRCW06031M00FKEA |  | SMD-0603 | 2 | https://robu.in/product/crcw06031m00fkea-vishay-intertech-100mw-thick-film-resistors-100v-%c2%b11-%c2%b1100ppm-%e2%84%83-1m%cf%89-0603-chip-resistor-surface-m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

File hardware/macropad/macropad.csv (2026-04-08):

Reference | Qty | Value | DNP | Exclude from BOM | Exclude from Board | Footprint | Datasheet | MPN
C1,C3,C7,C23,C26,C31 | 6 | 10u |  |  |  | Capacitor_SMD:C_0805_2012Metric | ~ | GRT21BR61C106KE01L
C2,C4,C5,C6,C8,C9,C11,C12,C14,C19,C20,C22,C24,C25 | 14 | 100n |  |  |  | Capacitor_SMD:C_0603_1608Metric | ~ | AC0603JRX7R9BB104
C10,C15,C17,C18 | 4 | 18p |  |  |  | Capacitor_SMD:C_0201_0603Metric | ~ | GCM0335C1H180FA16D
C13,C28 | 2 | 1u |  |  |  | Capacitor_SMD:C_0805_2012Metric | ~ | UMK212B7105KGHT
C16,C29 | 2 | 10n |  |  |  | Capacitor_SMD:C_0603_1608Metric | ~
C21,C30 | 2 | 2.2u |  |  |  | Capacitor_SMD:C_0603_1608Metric | ~ | TMK107BBJ225KAHT
C27 | 1 | 4.7u |  |  |  | Capacitor_SMD:C_0603_1608Metric | ~ | GRM188Z71C475KE21D
D1,D3 | 2 | LED |  |  |  | LED_SMD:LED_0805_2012Metric | ~ | 17-21SURC/S530-A3/4T
D2 | 1 | D_Schottky |  |  |  | Diode_SMD:D_SMA | ~ | SS34
J1 | 1 | SWD | DNP |  |  | Connector_PinHeader_2.54mm:PinHeader_1x04_P2.54mm_Vertical | ~
J2 | 1 | USB_C_Receptacle_USB2.0_16P |  |  |  | usbc:TYPE-C-SMD_U263-163N-4GS1735 | https://www.usb.org/sites/default/files/documents/usb_type-c.zip | U263-163N-4WS1735-XKB-5A
J3,J10 | 2 | Conn_01x02 | DNP |  |  | Connector_Hirose:Hirose_DF13-02P-1.25DSA_1x02_P1.25mm_Vertical | ~
J4 | 1 | display(4x1) | DNP |  |  | Connector_PinHeader_2.54mm:PinHeader_1x04_P2.54mm_Vertical | ~
J5 | 1 | Conn_01x04_Pin | DNP |  |  | Connector_PinHeader_2.54mm:PinHeader_1x04_P2.54mm_Horizontal | ~
J6 | 1 | Conn_01x03_Socket | DNP |  |  | Connector_Hirose:Hirose_DF13-03P-1.25DSA_1x03_P1.25mm_Vertical | ~
J8 | 1 | Conn_01x02 | DNP |  |  | Connector_Wire:SolderWire-0.5sqmm_1x02_P4.6mm_D0.9mm_OD2.1mm | ~
J9 | 1 | USB_A | DNP |  |  | usbA:U-G-O4DD-W-1 | ~
L1 | 1 | 2.2uH |  |  |  | Inductor_SMD:L_10.4x10.4_H4.8 | ~ | CDRH104R 2.2uH
Q1 | 1 | Q_PMOS |  |  |  | Package_TO_SOT_SMD:SOT-23-3 | ~ | SI2305CDS-T1-GE3
Q2 | 1 | FS8205A |  |  |  | FS8205A:SOP65P640X120-8N |  | FS8205A
R1,R3,R5,R11,R12,R13,R14,R17,R18,R19,R20,R23 | 12 | 10k |  |  |  | Resistor_SMD:R_0805_2012Metric | ~ | RC0805JR-0710KL
R2,R6 | 2 | 1.5k |  |  |  | Resistor_SMD:R_0603_1608Metric | ~ | RT0603FRE071K5L
R4,R7,R9 | 3 | 1k |  |  |  | Resistor_SMD:R_0603_1608Metric | ~ | AC0603FR-071KL
R8 | 1 | 1.2k |  |  |  | Resistor_SMD:R_0603_1608Metric | ~ | AC0603FR-071K2L
R10 | 1 | 100 |  |  |  | Resistor_SMD:R_0201_0603Metric | ~ | AC0201FR-07100RL
R15,R16,R24 | 3 | 5.1k |  |  |  | Resistor_SMD:R_0603_1608Metric | ~ | RT0603FRE075K1L
R21,R22 | 2 | 1M |  |  |  | Resistor_SMD:R_0603_1608Metric | ~ | CRCW06031M00FKEA
SW1,SW2,SW3,SW4,SW5,SW6,SW7,SW8,SW9 | 9 | SW_Push | DNP |  |  | keyswitches:Kailh_socket_MX | ~
SW10 | 1 | SW_SPDT | DNP |  |  | SS12F23L5:SS12F23L5 spdt | ~
SW12,SW13 | 2 | RotaryEncoder_Switch | DNP |  |  | Rotary_Encoder:RotaryEncoder_Alps_EC12E-Switch_Vertical_H20mm | ~ | KY-040
U1,U9 | 2 | LP2992IM5-3.3/NOPB |  |  |  | LP2992:DBV0005A_N | https://www.ti.com/lit/gpn/lp2992 | LP2992IM5-3.3/NOPB
U2,U4 | 2 | STM32F103C8Tx |  |  |  | Package_QFP:LQFP-48_7x7mm_P0.5mm | https://www.st.com/resource/en/datasheet/stm32f103c8.pdf | STM32F103C8T6
U3,U5 | 2 | NRF24L01_Breakout | DNP |  |  | nrf24l01:nRF24L01_Breakout | http://www.nordicsemi.com/eng/content/download/2730/34105/file/nRF24L01_Product_Specification_v2_0.pdf
U6 | 1 | TP4056-42-ESOP8 |  |  |  | Package_SO:SOIC-8-1EP_3.9x4.9mm_P1.27mm_EP2.41x3.3mm_ThermalVias | https://www.lcsc.com/datasheet/lcsc_datasheet_2410121619_TOPPOWER-Nanjing-Extension-Microelectronics-TP4056-42-ESOP8_C16581.pdf | TP4056
U7 | 1 | DW01A |  |  |  | Package_TO_SOT_SMD:SOT-23-6 | https://hmsemi.com/downfile/DW01A.PDF | DW01A
U10 | 1 | RT8010 |  |  |  | RT8010:WDFN-6L |  | RT8010-33GQW
Y1 | 1 | 8Mhz C_L=12pF |  |  |  | Crystal:Crystal_SMD_3225-4Pin_3.2x2.5mm | https://www.lcsc.com/datasheet/C2682775.pdf | X32258MOB4SI
Y2 | 1 | 8Mhz |  |  |  | Crystal:Crystal_SMD_3225-4Pin_3.2x2.5mm | https://www.lcsc.com/datasheet/C2682775.pdf | X32258MOB4SI

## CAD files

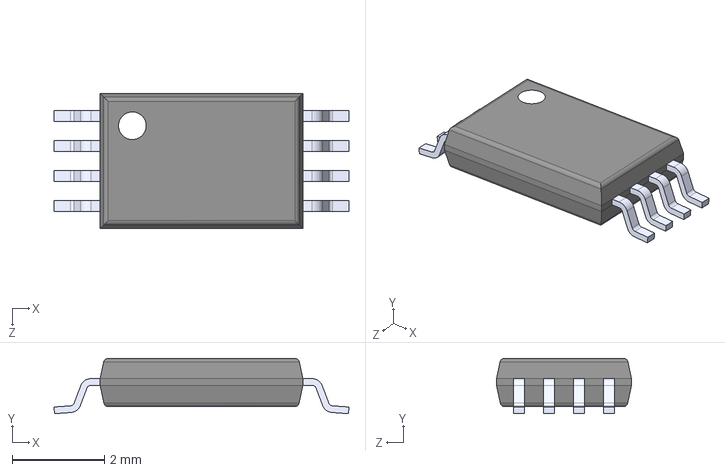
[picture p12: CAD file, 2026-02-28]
hardware/macropad/FS8205A/FS8205A.step
6.40 x 1.20 x 2.93 mm

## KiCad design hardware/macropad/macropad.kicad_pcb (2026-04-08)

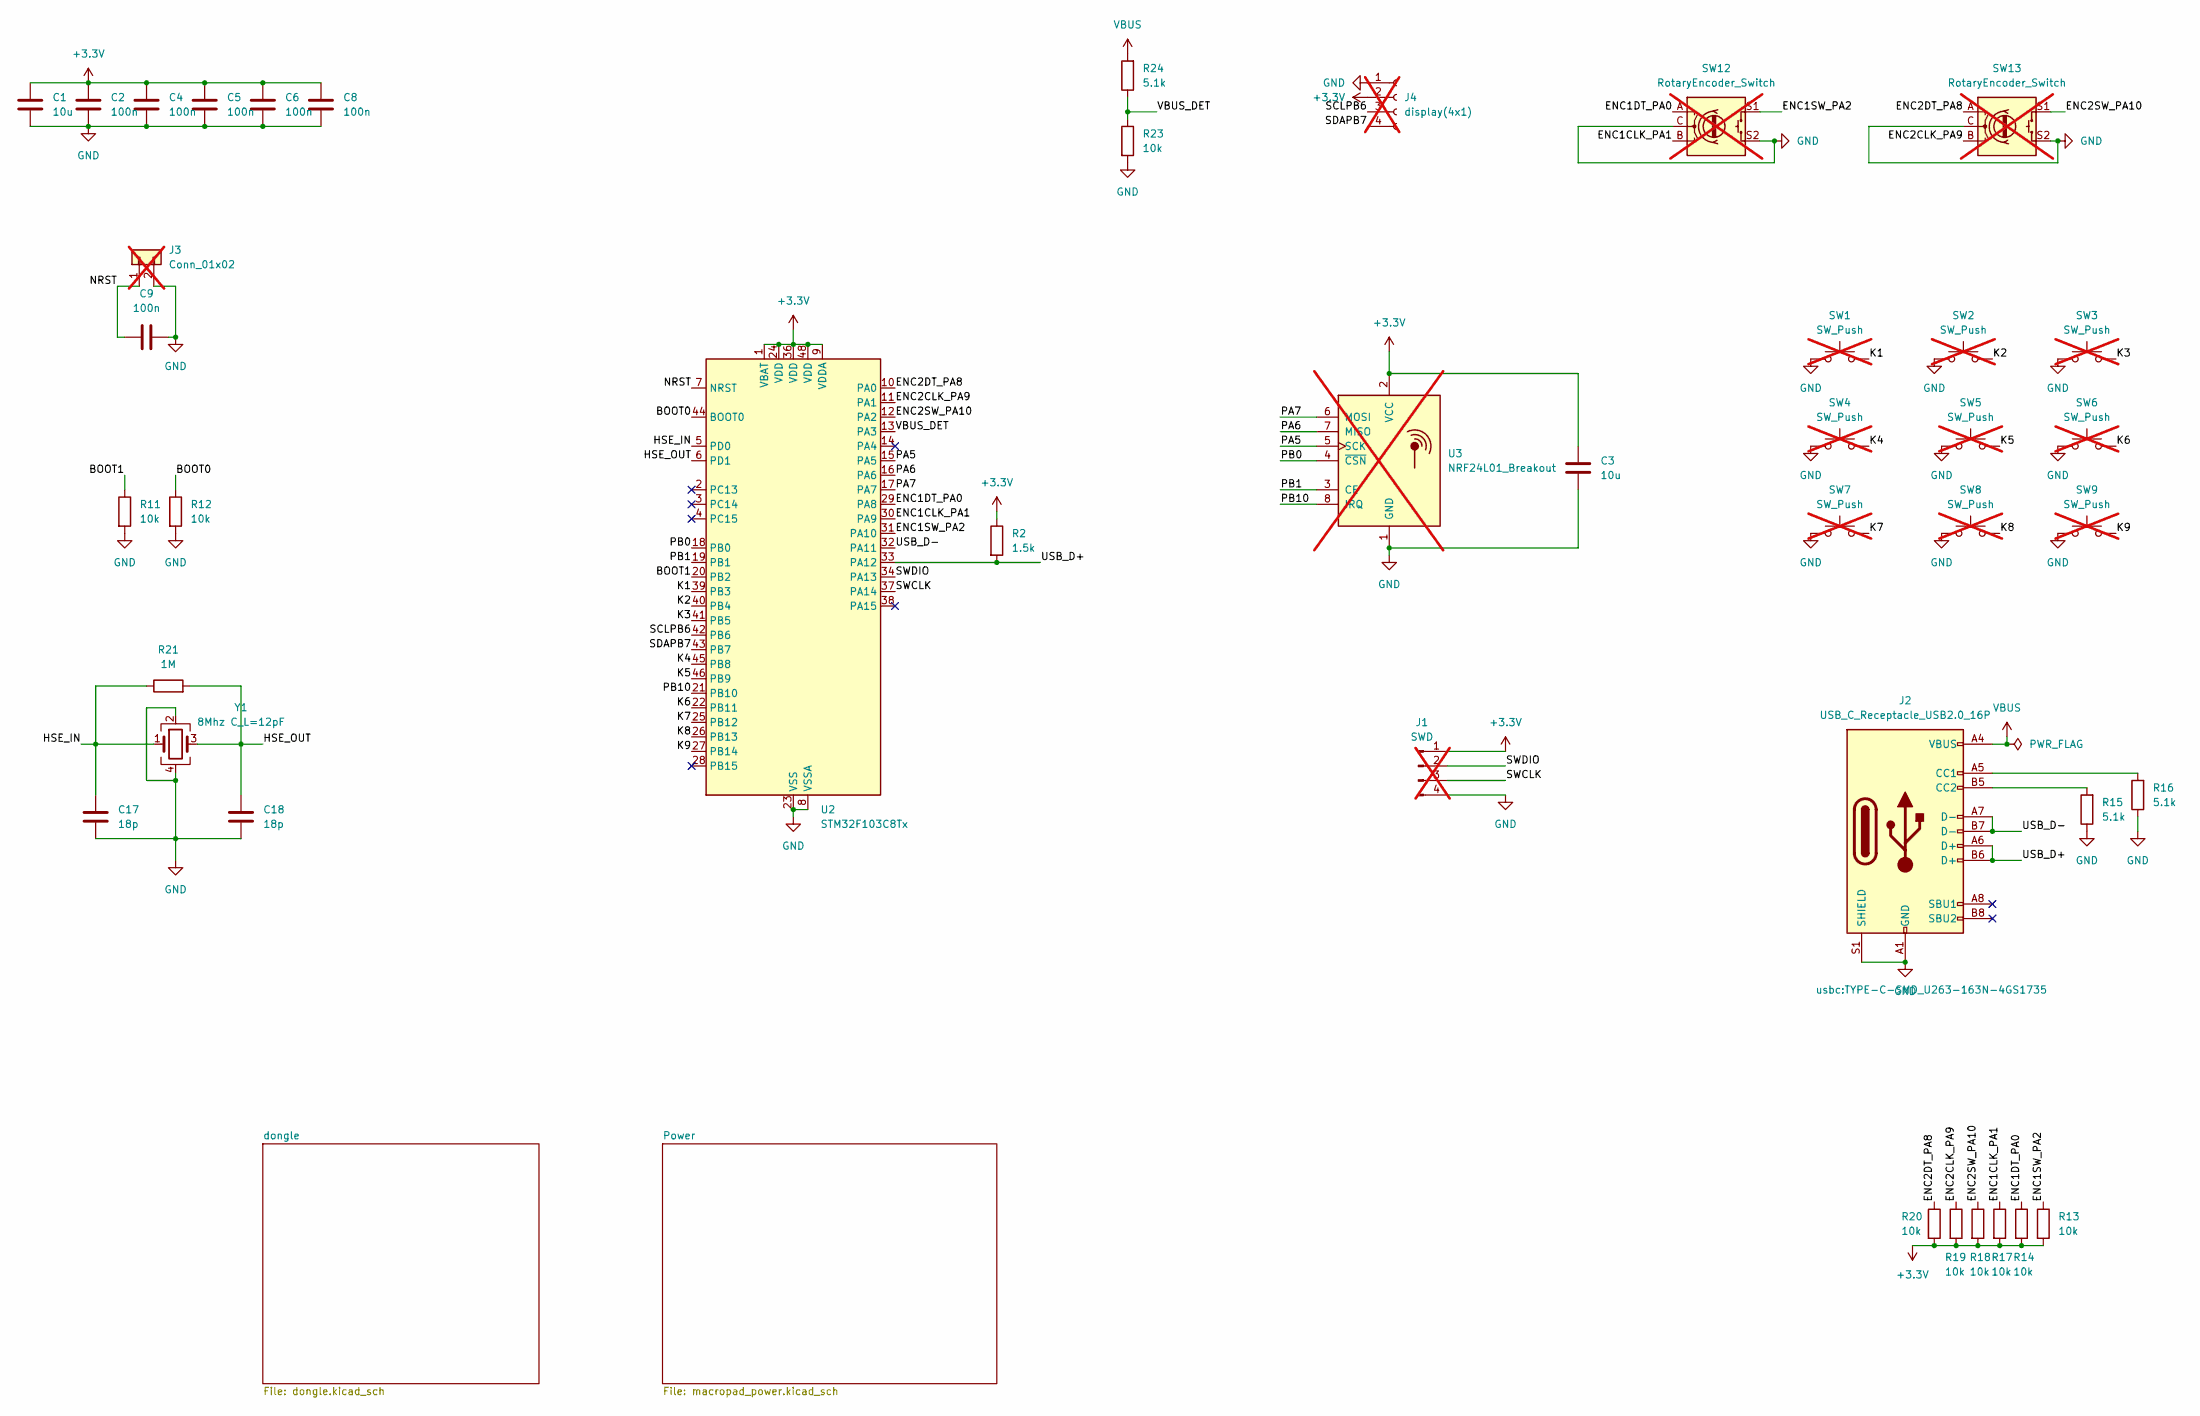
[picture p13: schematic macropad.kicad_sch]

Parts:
C1, C3: 10u; C_0805_2012Metric
C2, C4, C5, C6, C8, C9: 100n; C_0603_1608Metric
C17: 18p; C_0201_0603Metric
C18: 18p; C_0201_0603Metric; MPN GCM0335C1H180FA16D
J1: SWD; PinHeader_1x04_P2.54mm_Vertical; not fitted
J2: USB_C_Receptacle_USB2.0_16P; TYPE-C-SMD_U263-163N-4GS1735; MPN U263-163N-4WS1735-XKB-5A
J3: Conn_01x02; Hirose_DF13-02P-1.25DSA_1x02_P1.25mm_Vertical; not fitted
J4: display(4x1); PinHeader_1x04_P2.54mm_Vertical; not fitted
R2: 1.5k; R_0603_1608Metric
R11, R12, R14, R17, R18, R19, R20, R23: 10k; R_0805_2012Metric
R13: 10k; R_0805_2012Metric; MPN RC0805JR-0710KL
R15: 5.1k; R_0603_1608Metric; MPN RT0603FRE075K1L
R16, R24: 5.1k; R_0603_1608Metric
R21: 1M; R_0603_1608Metric
SW1, SW2, SW3, SW4, SW5, SW6, SW7, SW8, SW9: SW_Push; Kailh_socket_MX; not fitted
SW12: RotaryEncoder_Switch; RotaryEncoder_Alps_EC12E-Switch_Vertical_H20mm; MPN KY-040; not fitted
SW13: RotaryEncoder_Switch; RotaryEncoder_Alps_EC12E-Switch_Vertical_H20mm; not fitted
U2: STM32F103C8Tx; LQFP-48_7x7mm_P0.5mm; MPN STM32F103C8T6
U3: NRF24L01_Breakout; nRF24L01_Breakout; not fitted
Y1: 8Mhz C_L=12pF; Crystal_SMD_3225-4Pin_3.2x2.5mm; MPN X32258MOB4SI

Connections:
+3.3V: C1.1, C2.1, C3.1, C4.1, C5.1, C6.1, C8.1, J1.1, J4.2, R2.1, R13.2, R14.2, R17.2, R18.2, R19.2, R20.2, U2.1 (VBAT), U2.9 (VDDA), U2.24 (VDD), U2.36 (VDD), U2.48 (VDD), U3.2 (VCC); also elsewhere on the board
/BOOT0: R12.1, U2.44 (BOOT0)
/BOOT1: R11.1, U2.20 (PB2)
/ENC1CLK_PA1: R17.1, SW12.B, U2.30 (PA9)
/ENC1DT_PA0: R14.1, SW12.A, U2.29 (PA8)
/ENC1SW_PA2: R13.1, SW12.S1, U2.31 (PA10)
/ENC2CLK_PA9: R19.1, SW13.B, U2.11 (PA1)
/ENC2DT_PA8: R20.1, SW13.A, U2.10 (PA0)
/ENC2SW_PA10: R18.1, SW13.S1, U2.12 (PA2)
/HSE_IN: C17.1, R21.1, U2.5 (PD0), Y1.1
/HSE_OUT: C18.1, R21.2, U2.6 (PD1), Y1.3
/K1: SW1.2, U2.39 (PB3)
/K2: SW2.2, U2.40 (PB4)
/K3: SW3.2, U2.41 (PB5)
/K4: SW4.2, U2.45 (PB8)
/K5: SW5.2, U2.46 (PB9)
/K6: SW6.2, U2.22 (PB11)
/K7: SW7.2, U2.25 (PB12)
/K8: SW8.2, U2.26 (PB13)
/K9: SW9.2, U2.27 (PB14)
/NRST: C9.2, J3.1, U2.7 (NRST)
/PA5: U2.15 (PA5), U3.5 (SCK)
/PA6: U2.16 (PA6), U3.7 (MISO)
/PA7: U2.17 (PA7), U3.6 (MOSI)
/PB0: U2.18 (PB0), U3.4 (~CSN)
/PB1: U2.19 (PB1), U3.3 (CE)
/PB10: U2.21 (PB10), U3.8 (IRQ)
/SCLPB6: J4.3, U2.42 (PB6)
/SDAPB7: J4.4, U2.43 (PB7)
/SWCLK: J1.3, U2.37 (PA14)
/SWDIO: J1.2, U2.34 (PA13)
/USB_D+: J2.A6 (D+), J2.B6 (D+), R2.2, U2.33 (PA12)
/USB_D-: J2.A7 (D-), J2.B7 (D-), U2.32 (PA11)
/VBUS_DET: R23.1, R24.1, U2.13 (PA3)
GND: C1.2, C2.2, C3.2, C4.2, C5.2, C6.2, C8.2, C9.1, C17.2, C18.2, J1.4, J2.A1 (GND), J2.A12 (GND), J2.B1 (GND), J2.B12 (GND), J2.S1 (SHIELD), J3.2, J4.1, R11.2, R12.2, R15.1, R16.1, R23.2, SW1.1, SW2.1, SW3.1, SW4.1, SW5.1, SW6.1, SW7.1, SW8.1, SW9.1, SW12.C, SW12.S2, SW13.C, SW13.S2, U2.8 (VSSA), U2.23 (VSS), U2.35 (VSS), U2.47 (VSS), U3.1 (GND), Y1.2, Y1.4; also elsewhere on the board
unnamed: J2.A5 (CC1), R16.2
unnamed: J2.B5 (CC2), R15.2
VBUS: J2.A4 (VBUS), J2.A9 (VBUS), J2.B4 (VBUS), J2.B9 (VBUS), R24.2; also elsewhere on the board

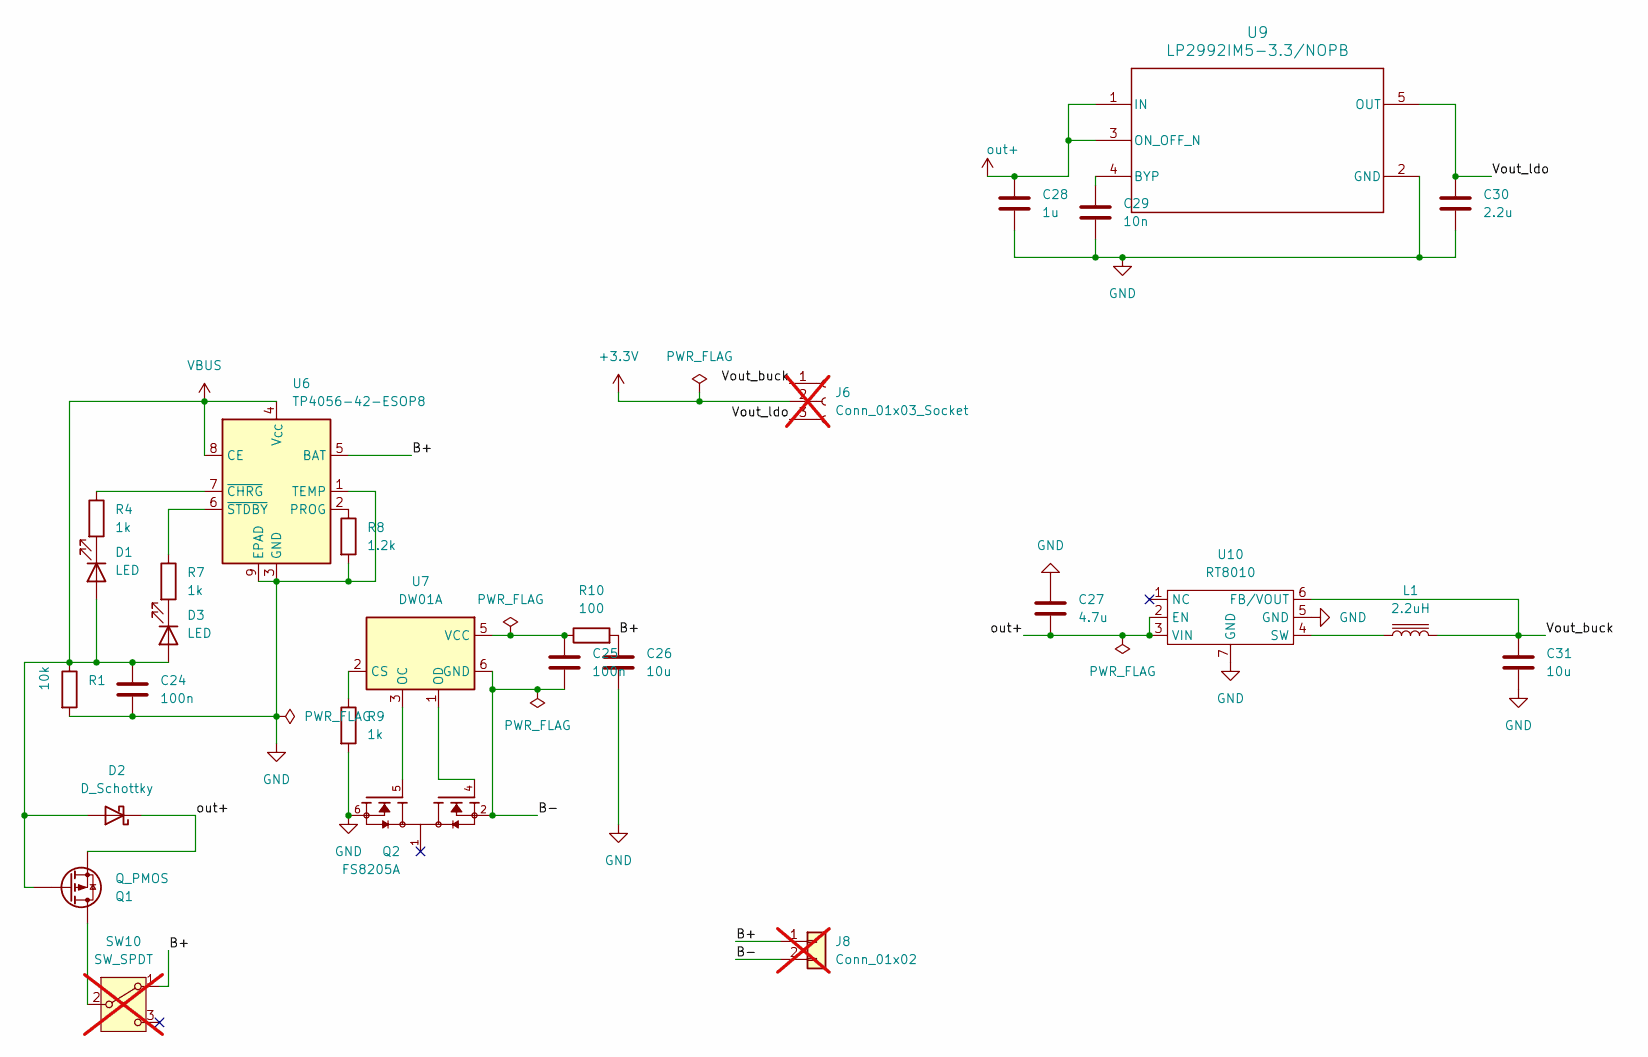
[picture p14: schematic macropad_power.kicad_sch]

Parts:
C24: 100n; C_0603_1608Metric; MPN AC0603JRX7R9BB104
C25: 100n; C_0603_1608Metric
C26: 10u; C_0805_2012Metric; MPN GRT21BR61C106KE01L
C27: 4.7u; C_0603_1608Metric; MPN GRM188Z71C475KE21D
C28: 1u; C_0805_2012Metric
C29: 10n; C_0603_1608Metric
C30: 2.2u; C_0603_1608Metric; MPN TMK107BBJ225KAHT
C31: 10u; C_0805_2012Metric
D1: LED; LED_0805_2012Metric
D2: D_Schottky; D_SMA; MPN SS34
D3: LED; LED_0805_2012Metric; MPN 17-21SURC/S530-A3/4T
J6: Conn_01x03_Socket; Hirose_DF13-03P-1.25DSA_1x03_P1.25mm_Vertical; not fitted
J8: Conn_01x02; SolderWire-0.5sqmm_1x02_P4.6mm_D0.9mm_OD2.1mm; not fitted
L1: 2.2uH; L_10.4x10.4_H4.8; MPN CDRH104R 2.2uH
Q1: Q_PMOS; SOT-23-3; MPN SI2305CDS-T1-GE3
Q2: FS8205A; SOP65P640X120-8N; PARTREV 1.7
R1: 10k; R_0805_2012Metric
R4, R7: 1k; R_0603_1608Metric
R8: 1.2k; R_0603_1608Metric; MPN AC0603FR-071K2L
R9: 1k; R_0603_1608Metric; MPN AC0603FR-071KL
R10: 100; R_0201_0603Metric; MPN AC0201FR-07100RL
SW10: SW_SPDT; SS12F23L5 spdt; not fitted
U6: TP4056-42-ESOP8; SOIC-8-1EP_3.9x4.9mm_P1.27mm_EP2.41x3.3mm_ThermalVias; MPN TP4056
U7: DW01A; SOT-23-6; MPN DW01A
U9: LP2992IM5-3.3/NOPB; DBV0005A_N; MPN LP2992IM5-3.3/NOPB
U10: RT8010; WDFN-6L; MPN RT8010-33GQW

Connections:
+3.3V: J6.2; also elsewhere on the board
/Power/B+: C26.1, J8.1, R10.2, SW10.1 (A), U6.5 (BAT)
/Power/B-: C25.2, J8.2, Q2.2, Q2.3, U7.6 (GND)
/Power/Vout_buck: C31.1, J6.1, L1.2, U10.6 (FB/VOUT)
/Power/Vout_ldo: C30.1, J6.3, U9.5 (OUT)
GND: C24.2, C26.2, C27.1, C28.2, C29.2, C30.2, C31.2, Q2.6, Q2.7, R1.2, R8.2, R9.2, U6.1 (TEMP), U6.3 (GND), U6.9 (EPAD), U9.2 (GND), U10.5 (GND), U10.7 (GND); also elsewhere on the board
unnamed: D1.1 (K), R4.2
unnamed: D3.1 (K), R7.2
unnamed: Q1.3 (D), SW10.2 (B)
unnamed: R8.1, U6.2 (PROG)
unnamed: R4.1, U6.7 (~CHRG)
unnamed: R7.1, U6.6 (~STDBY)
unnamed: R9.1, U7.2 (CS)
unnamed: Q2.5, U7.3 (OC)
unnamed: Q2.4, U7.1 (OD)
unnamed: C25.1, R10.1, U7.5 (VCC)
unnamed: C29.1, U9.4 (BYP)
unnamed: L1.1, U10.4 (SW)
VBUS: C24.1, D1.2 (A), D2.2 (A), D3.2 (A), Q1.1 (G), R1.1, U6.4 (V_{CC}), U6.8 (CE); also elsewhere on the board
out+: C27.2, C28.1, D2.1 (K), Q1.2 (S), U9.1 (IN), U9.3 (ON_OFF_N), U10.2 (EN), U10.3 (VIN)

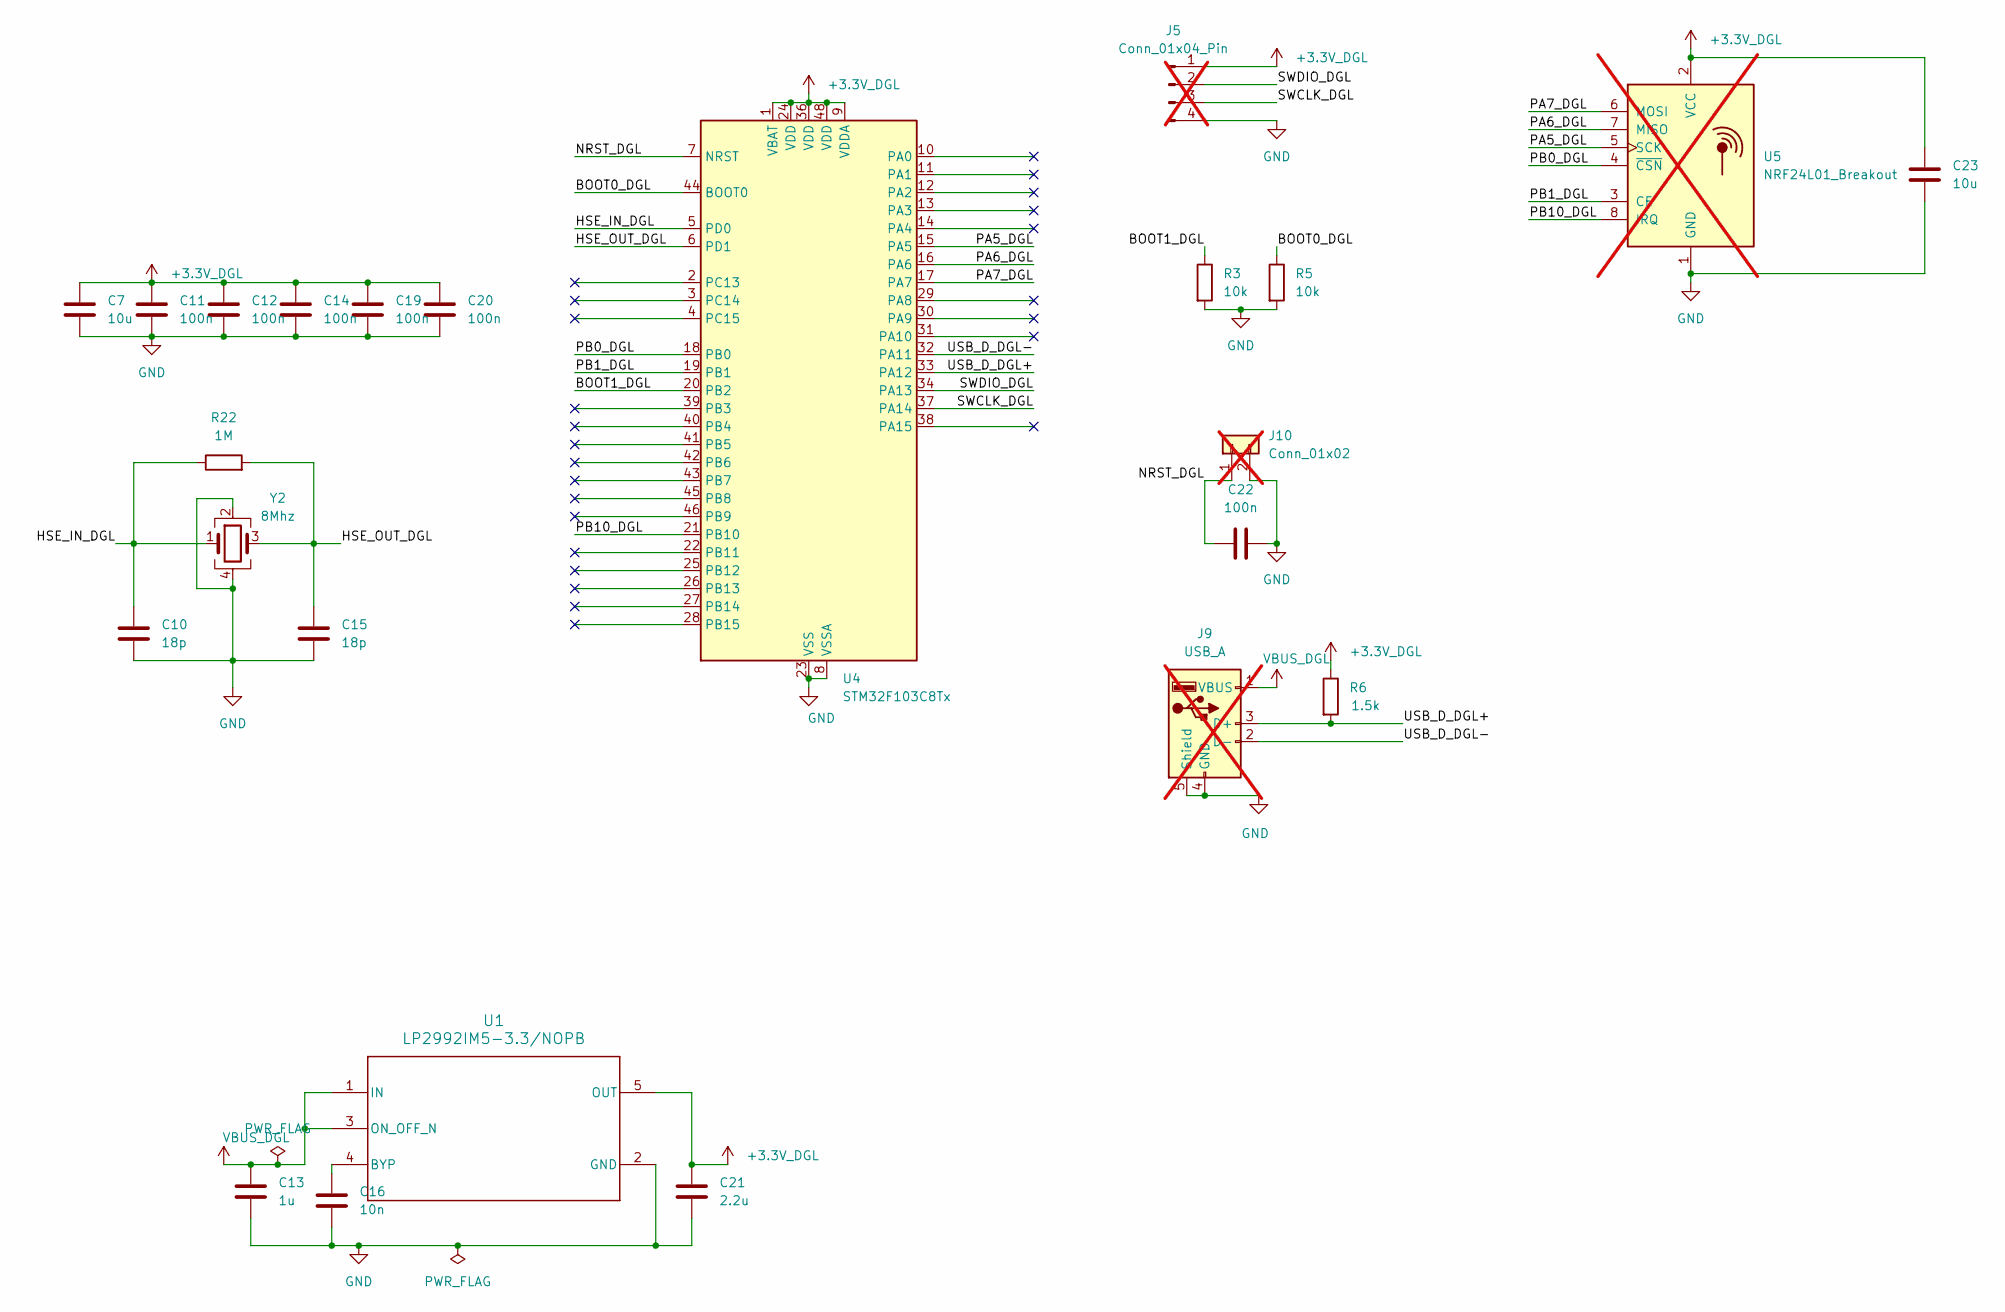
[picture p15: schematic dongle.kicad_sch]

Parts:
C7, C23: 10u; C_0805_2012Metric
C10, C15: 18p; C_0201_0603Metric
C11, C12, C14, C19, C20, C22: 100n; C_0603_1608Metric
C13: 1u; C_0805_2012Metric; MPN UMK212B7105KGHT
C16: 10n; C_0603_1608Metric
C21: 2.2u; C_0603_1608Metric
J5: Conn_01x04_Pin; PinHeader_1x04_P2.54mm_Horizontal; not fitted
J9: USB_A; U-G-O4DD-W-1; not fitted
J10: Conn_01x02; Hirose_DF13-02P-1.25DSA_1x02_P1.25mm_Vertical; not fitted
R3, R5: 10k; R_0805_2012Metric
R6: 1.5k; R_0603_1608Metric; MPN RT0603FRE071K5L
R22: 1M; R_0603_1608Metric; MPN CRCW06031M00FKEA
U1: LP2992IM5-3.3/NOPB; DBV0005A_N
U4: STM32F103C8Tx; LQFP-48_7x7mm_P0.5mm
U5: NRF24L01_Breakout; nRF24L01_Breakout; not fitted
Y2: 8Mhz; Crystal_SMD_3225-4Pin_3.2x2.5mm; MPN X32258MOB4SI

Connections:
+3.3V_DGL: C7.1, C11.1, C12.1, C14.1, C19.1, C20.1, C21.1, C23.1, J5.1, R6.1, U1.5 (OUT), U4.1 (VBAT), U4.9 (VDDA), U4.24 (VDD), U4.36 (VDD), U4.48 (VDD), U5.2 (VCC)
/dongle/BOOT0_DGL: R5.1, U4.44 (BOOT0)
/dongle/BOOT1_DGL: R3.1, U4.20 (PB2)
/dongle/HSE_IN_DGL: C10.1, R22.1, U4.5 (PD0), Y2.1
/dongle/HSE_OUT_DGL: C15.1, R22.2, U4.6 (PD1), Y2.3
/dongle/NRST_DGL: C22.2, J10.1, U4.7 (NRST)
/dongle/PA5_DGL: U4.15 (PA5), U5.5 (SCK)
/dongle/PA6_DGL: U4.16 (PA6), U5.7 (MISO)
/dongle/PA7_DGL: U4.17 (PA7), U5.6 (MOSI)
/dongle/PB0_DGL: U4.18 (PB0), U5.4 (~CSN)
/dongle/PB1_DGL: U4.19 (PB1), U5.3 (CE)
/dongle/PB10_DGL: U4.21 (PB10), U5.8 (IRQ)
/dongle/SWCLK_DGL: J5.3, U4.37 (PA14)
/dongle/SWDIO_DGL: J5.2, U4.34 (PA13)
/dongle/USB_D_DGL+: J9.3 (D+), R6.2, U4.33 (PA12)
/dongle/USB_D_DGL-: J9.2 (D-), U4.32 (PA11)
GND: C7.2, C10.2, C11.2, C12.2, C13.2, C14.2, C15.2, C16.2, C19.2, C20.2, C21.2, C22.1, C23.2, J5.4, J9.4 (GND), J9.5 (Shield), J10.2, R3.2, R5.2, U1.2 (GND), U4.8 (VSSA), U4.23 (VSS), U4.35 (VSS), U4.47 (VSS), U5.1 (GND), Y2.2, Y2.4; also elsewhere on the board
unnamed: C16.1, U1.4 (BYP)
VBUS_DGL: C13.1, J9.1 (VBUS), U1.1 (IN), U1.3 (ON_OFF_N)

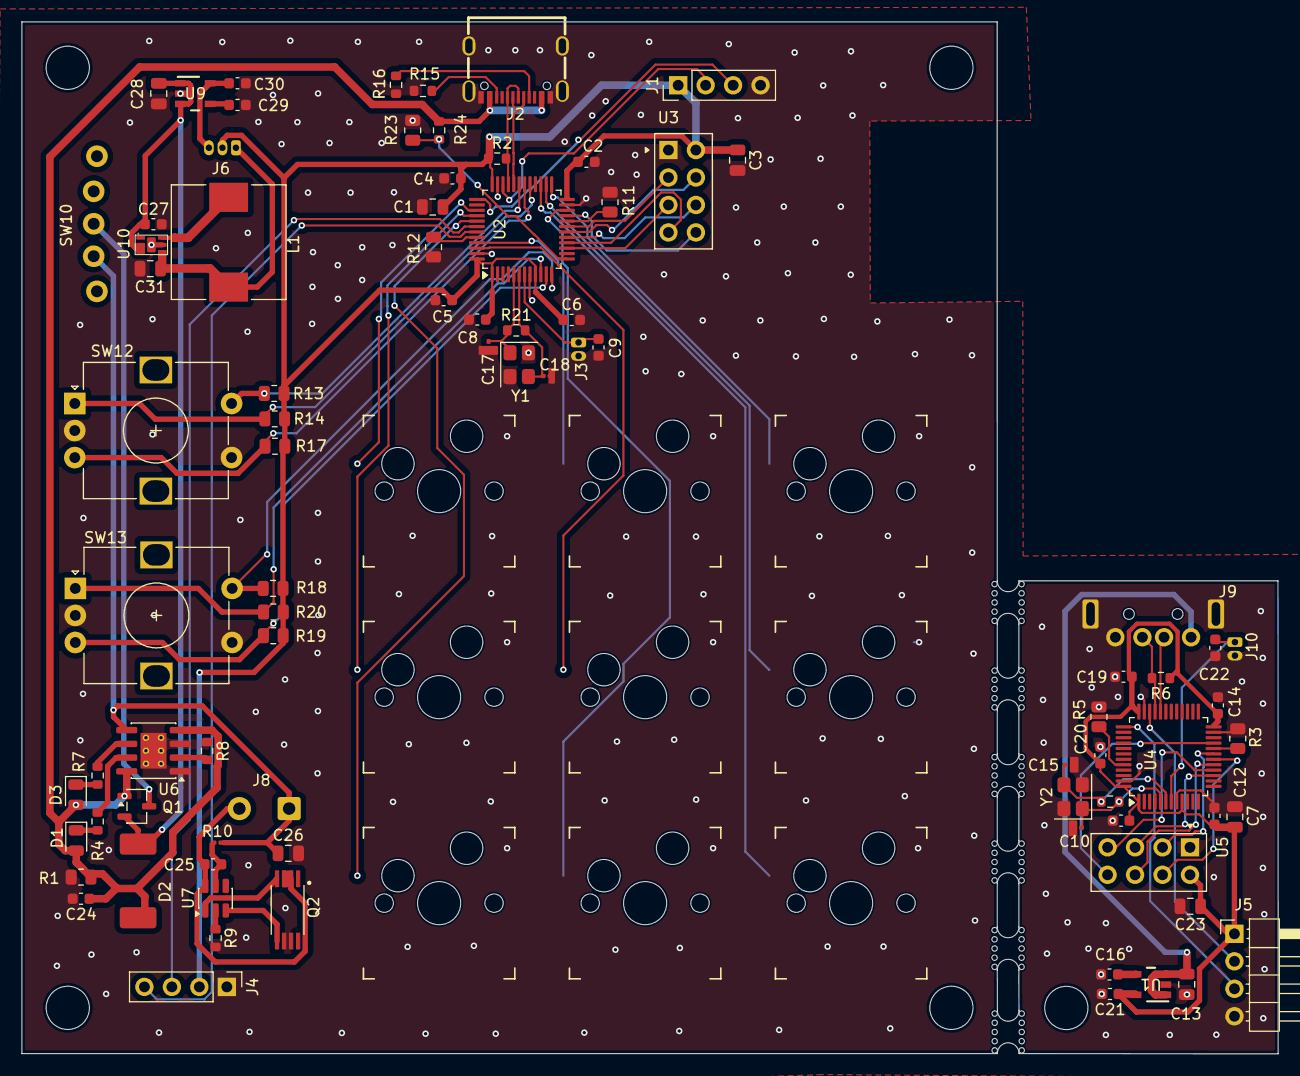
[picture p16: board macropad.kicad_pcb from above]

Board: 2 copper layers, 116.2 x 95.4 mm, 93 parts (1 on the bottom side), 73 nets.

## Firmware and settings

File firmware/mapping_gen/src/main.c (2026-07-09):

#include <stdbool.h>
#include <stdio.h>
#include <stdlib.h>
#include <string.h>

#include "defs.h"
#include "json_parser.h"
#include "gui.h"

#if defined(_WIN32) || defined(_WIN64)
#define NULL_DEVICE "NUL"
#else
#define NULL_DEVICE "/dev/null"
#endif

void print_usage(const char *prog_name)
{
    printf("Macro Pad Layout JSON Compiler\n");
    printf("Usage: %s [options] [input_file.json]\n\n", prog_name);
    printf("Options:\n");
    printf("  -h, --help           Show this help message and exit\n");
    printf("  -c, --compile-only   Only generate 'mappings.bin' file without flashing via dfu-util\n");
    printf("  -v, --verbose        Show process logs during execution\n\n");
    printf("  -g, --gui            Open GUI\n\n");
    printf("Arguments:\n");
    printf("  [input_file.json]    Path to layout JSON (defaults to 'layout.json')\n");
}

int main(int argc, char *argv[])
{
    const char *input_filename = "layout.json";
    bool compile_only = false;
    bool verbose = false;
    bool gui = false;

    for (int i = 1; i < argc; i++)
    {
        if (strcmp(argv[i], "--help") == 0 || strcmp(argv[i], "-h") == 0)
        {
            print_usage(argv[0]);
            return 0;
        }
        else if (strcmp(argv[i], "--compile-only") == 0 || strcmp(argv[i], "-c") == 0)
        {
            compile_only = true;
        }
        else if (strcmp(argv[i], "--verbose") == 0 || strcmp(argv[i], "-v") == 0)
        {
            verbose = true;
        }
        else if (strcmp(argv[i], "--gui") == 0 || strcmp(argv[i], "-g") == 0)
        {
            gui=true;
        }
        else
        {
            input_filename = argv[i];
        }
    }

    printf("Loading layout config from: %s\n", input_filename);
    if(gui) call_gui(input_filename);

    mappings_t *map = NULL;
    size_t total_bin_size = 0;

    if (parse_json_layout(input_filename, &map, &total_bin_size) != 0)
    {
        printf("Failed to parse JSON file layout configurations. Run '%s --help' for template guide.\n", argv[0]);
        return 1;
    }

    const char *output_filename = compile_only ? "mappings.bin" : ".tmp_mappings.bin";
    FILE *outfile = fopen(output_filename, "wb");
    if (!outfile)
    {
        perror("Failed to generate file output binary target");
        free(map);
        return 1;
    }

    size_t written = fwrite(map, 1, total_bin_size, outfile);
    fclose(outfile);
    free(map);

    if (compile_only)
    {
        printf("Successfully compiled layout structure!\n");
        printf("Total Binary Payload Size: %zu bytes\n", written);
        printf("Flash Output Location Target: 0x%08X\n", MAPPINGS_ADDR);
    }
    else
    {
        printf("Binary prepared (%zu bytes). Invoking dfu-util...\n", written);

        char dfu_command[256];
        if (verbose)
        {
            snprintf(dfu_command, sizeof(dfu_command), "dfu-util -d 1209:1253 -a 1 -D %s", output_filename);
        }
        else
        {
            snprintf(dfu_command, sizeof(dfu_command), "dfu-util -d 1209:1253 -a 1 -D %s > %s 2>&1", output_filename,
                     NULL_DEVICE);
        }

        if (verbose)
            printf("Executing: %s\n", dfu_command);

        int status = system(dfu_command);

        remove(output_filename);

        if (status == 0)
        {
            printf("\nFlash complete! Layout successfully deployed to macro pad.\n");
        }
        else
        {
            fprintf(stderr, "\nError: dfu-util flashing failed (Exit code: %d).\n", status);
            fprintf(stderr, "Ensure your macro pad is in DFU bootloader mode and try again.\n");
            return 1;
        }
    }

    return 0;
}

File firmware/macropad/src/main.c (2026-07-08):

#include <stddef.h>

#include <libopencm3/stm32/flash.h>
#include <libopencm3/stm32/rcc.h>
#include <libopencm3/cm3/scb.h>
#include <stdint.h>

#include "defs.h"
#include "control.h"
#include "display.h"
#include "input.h"
#include "time.h"
#include "usb.h"

static void init(void)
{
	SCB_VTOR = START_ADDR;

	rcc_clock_setup_pll(&rcc_hse_configs[RCC_CLOCK_HSE8_72MHZ]);
}

int main(void)
{
	for (int i=0;i<80000;i++) __asm__ volatile ("nop");
	init();

	time_init();

	display_init();
	display_iit(54,2);
	display_string(50, 5, "IITH PAD\0");

	display_update_all();

	for (int i=0;i<8000000;i++) __asm__ volatile ("nop");

	if(control_init() != 0)
	{
		flash_unlock();
		flash_erase_page(LAST_PAGE);
		flash_program_word(LAST_PAGE, (uint32_t)MAGIC);
		flash_lock();

		scb_reset_system();
	}

	usb_init();
	input_init();

	while(1)
	{
		input_poll();
		display_update_chunk();
		usb_run();
	}
}

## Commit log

2026-02-26 added some things like power
    [macropad.kicad_sch]
2026-02-26 peripherals connected passive,keys still to be done
    [macropad.kicad_sch]
2026-02-26 added firmware, gitignore; removed dongle kicad project
    [dongle.kicad_pcb, dongle.kicad_sch, macropad.kicad_pcb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]
2026-02-26 switches added. folders deleted
    [macropad.kicad_pcb, macropad.kicad_sch]
2026-02-26 switches fixed
    [macropad.kicad_sch]
2026-02-26 added reset and 3x2 connector
    [macropad.kicad_sch]
2026-02-27 schema added for dongle. rearranged some parts
    [dongle.kicad_sch, macropad.kicad_sch]
2026-02-27 schematic halfass done
    [dongle.kicad_sch, macropad.kicad_pcb, macropad.kicad_sch]
2026-02-28 ERC satisfied. Net names changed for not global
    [dongle.kicad_sch]
2026-02-28 removed keyswitch pullups
    [dongle.kicad_sch, macropad.kicad_sch]
2026-02-28 switched to usb-c receptacle
    [macropad.kicad_sch]
2026-02-28 added new sch
    [macropad_power.kicad_sch]
2026-02-28 moved powering circuitry to new schematic
    [dongle.kicad_sch, macropad.kicad_sch, macropad_power.kicad_sch]
2026-02-28 captured TP4056 module
    [FS8205A.step, macropad_power.kicad_sch]
2026-02-28 captured the Buck(3_3V)
    [macropad_power.kicad_sch]
2026-03-01 added debouncing caps
    [dongle.kicad_sch, macropad.kicad_sch, macropad_power.kicad_sch]
2026-03-01 added 1k resistors to leds
    [macropad_power.kicad_sch]
2026-03-01 changed load capacitance, added oscillator for pad
    [dongle.kicad_sch, macropad.kicad_sch, macropad_power.kicad_sch]
2026-03-01 update oscillator + passives'
    [dongle.kicad_sch, macropad.kicad_sch]
2026-03-01 something changed. i didnt track
    [dongle.kicad_sch, macropad.kicad_sch]
2026-03-02 updated footprints
    [dongle.kicad_sch, macropad.csv, macropad.kicad_sch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]
2026-03-03 replaced enc with module
    [macropad.kicad_sch]
2026-03-03 updated bat switch, added 10k resistors. fixed fps
    [dongle.kicad_sch, macropad.kicad_sch, macropad_power.kicad_sch]
2026-03-03 updated lp2992
    [dongle.kicad_sch]
2026-03-04 added usb-c receptacle footprint
    [dongle.kicad_sch, macropad.kicad_pcb, macropad.kicad_sch]
2026-03-04 updated symbols. changed power. erc fixxed halfway
    [dongle.kicad_sch, macropad_power.kicad_sch]
2026-03-05 erc for power checked
    [macropad_power.kicad_sch]
2026-03-05 erc for macropad checked
    [macropad.kicad_sch, macropad_power.kicad_sch]
2026-03-05 updated symbols. all erc passed
    [macropad_power.kicad_sch]
2026-03-05 added usba fp, updated pcb, 5v to vbus
    [dongle.kicad_sch, macropad.kicad_pcb, macropad.kicad_sch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]
2026-03-06 replaced buttons with pads
    [dongle.kicad_sch, macropad.kicad_pcb, macropad.kicad_sch]
2026-03-06 updated usb-c receptacle footprint
    [macropad.kicad_pcb, macropad.kicad_sch]
2026-03-11 updated. comments in whatsapp
    [dongle.kicad_sch, macropad.kicad_pcb, macropad.kicad_sch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]
2026-03-12 updated pcb with switch
    [macropad.kicad_pcb, macropad_power.kicad_sch]
2026-03-12 pcb macropad done
    [macropad.kicad_pcb, macropad.kicad_sch, macropad_power.kicad_sch]
2026-03-12 pcb done
    [macropad.kicad_pcb, macropad.kicad_sch]
2026-03-16 Updated Layout
    [macropad.kicad_pcb]
2026-03-18 wrote code for testing i2c with ssd1306
2026-03-18 updated schematic and drc
    [dongle.kicad_sch, macropad.csv, macropad.kicad_pcb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]
2026-03-18 Macropad layout kinda done
    [dongle.kicad_sch, macropad.kicad_pcb, macropad.kicad_sch]
2026-03-19 added drc
    [macropad.kicad_pcb]
2026-03-19 rt8010 footprint
2026-03-19 rt8010 footprint+symbol done
2026-03-19 routing phase 2
    [macropad.kicad_pcb, macropad_power.kicad_sch]
2026-03-26 updated dongle
    [dongle.kicad_sch, macropad.kicad_pcb, macropad_power.kicad_sch]
2026-04-01 changes made
    [macropad.kicad_pcb]
2026-04-01 schottkey updated and added mount hole
    [macropad.kicad_pcb]
2026-04-02 added single pad usbc footprint
2026-04-02 added hole
    [macropad-B_Cu.gbr, macropad-B_Mask.gbr, macropad-B_Paste.gbr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]
2026-04-04 stitching done
    [dongle.kicad_sch, macropad.kicad_pcb, macropad.kicad_sch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]
2026-04-06 fab outputs
    [dongle.kicad_sch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]
2026-04-08 proper fab outs
    [dongle.kicad_sch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]
2026-04-08 fixed technical queries
    [dongle.kicad_sch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]
2026-05-10 Updated BOM and Proposal
    [BOM.csv]
2026-06-25 Update project status and add 3D printing tasks
    Updated project status in the README with completed tasks and added new 3D printing tasks.
2026-06-25 Fixed bootloader dfu altsetting and mapping_gen keycodes
    [dfu.c, main.c]
2026-06-29 added disp-layer call, keys not working
    [display.c, main.c]
2026-06-30 Updated layer switching; added layer menu mode
